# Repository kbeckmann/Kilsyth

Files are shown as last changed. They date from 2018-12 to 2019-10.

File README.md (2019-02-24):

# WIP! WIP! WIP! 
This repo is a work in progress and far from release-worthy. Please don't make your own boards and expect any kind of support. However, it might reach a stable point sometime in the future (as of 2019-01).

# Kilsyth: ECP5 FPGA + FT60x FIFO
Kilsyth is a piece of hardware that contains an FPGA (Lattice ECP5) and a SuperSpeed USB 3.0 FIFO-bridge (FT60x). The goal is to provide a platform to be able to transfer high speed data transfers between a PC and an FPGA. The FPGA in turn can do whatever - e.g. interface with SDR, video capture, act as a logic analyzer.

## Current status
It's still in the early bring-up phase. Initial verification shows that it actually seems to work.

### RevA
RevA is the first prototype and has been designed and built.

- [x] It doesn't smoke when powered up.
- [x] USB-C connector works but is messy to solder.
- [ ] Loopback test is almost in place. Using the proprietary driver, high bi-directional speeds are achieavable (> 98MB/s in both directions simultaneously). Just need to figure out some off-by-one errors...
- [ ] Bootloader to store a custom bitstream on the flash.

Errata:
- C9 is not a GPIO on ECP5 F12 and some other variants. To get the LED working put a jumper on pin 31 and 33 on the Wide connector.
- FT_CLK is not routed to a clock pin. Can be fixed with a bodge wire! Remove R50 and R36, swap their paths.
- JTAG connector has a funky footprint on the PCB because CCW vs Odd/Even pinout on the symbol vs footprint. But the PCB silk screen is accurate so don't worry - it's just a stupid pinout.
- Need to add pull-ups for the SPI flash.

### RevB
Ideas for RevB are still being collected. Feel free to suggest changes in an issue.

- Add support for reversible USB-C connector using [PI5USB30213A](https://www.diodes.com/products/connectivity-and-timing/switches-mux/protocol-switches/usb-switches/part/PI5USB30213A).

## Software usage (TODO)

Requires a patched migen and a patched ftdi library.. Nasty, I know, sorry.

```
Help:
$ python -m software.kilsyth -h

Run blinky:
$ python -m software.kilsyth run blinky

```

# Contact

Reach out to [@kbeckmann](https://twitter.com/kbeckmann) on Twitter or IRC/Freenode.

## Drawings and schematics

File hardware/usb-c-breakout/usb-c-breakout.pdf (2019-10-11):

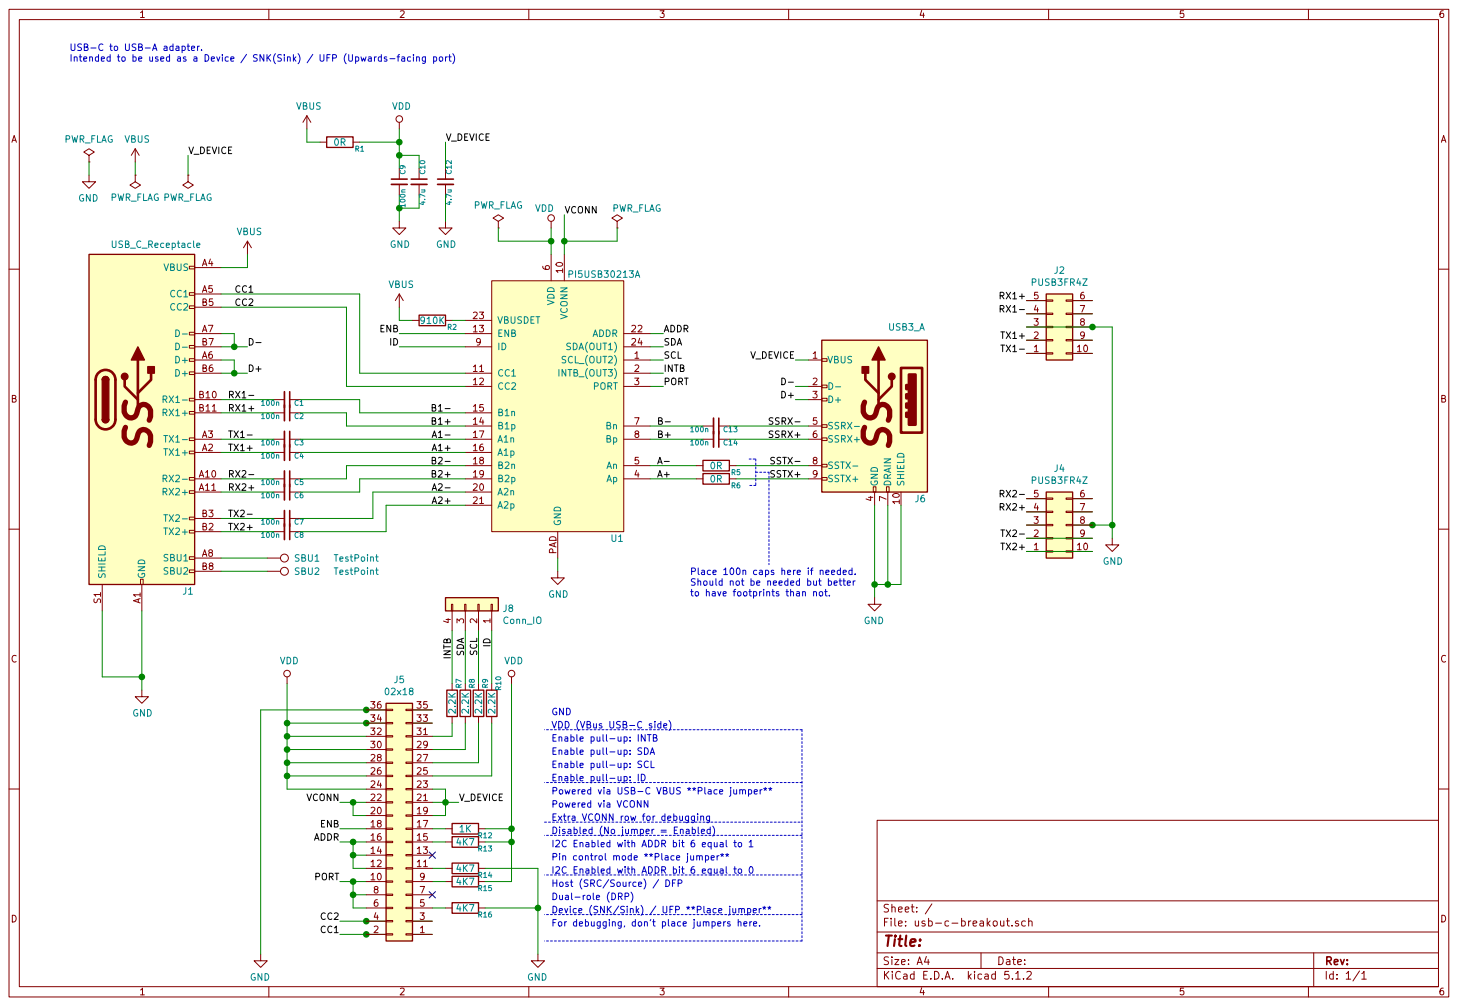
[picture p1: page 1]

USB-C to USB-A adapter.

to have footprints than not. R5 0R

Place 100n caps here if needed. Should not be needed but better

Enable pull-up: INTB
Enable pull-up: SDA
Enable pull-up: SCL
Enable pull-up: ID
Powered via USB-C VBUS **Place jumper**
For debugging, don't place jumpers here. Powered via VCONN
Extra VCONN row for debugging
Disabled (No jumper = Enabled)
I2C Enabled with ADDR bit 6 equal to 1
Pin control mode **Place jumper**
I2C Enabled with ADDR bit 6 equal to 0
Host (SRC/Source) / DFP
Dual-role (DRP)
Device (SNK/Sink) / UFP **Place jumper**

28 | 27
26 | 25
24 | 23

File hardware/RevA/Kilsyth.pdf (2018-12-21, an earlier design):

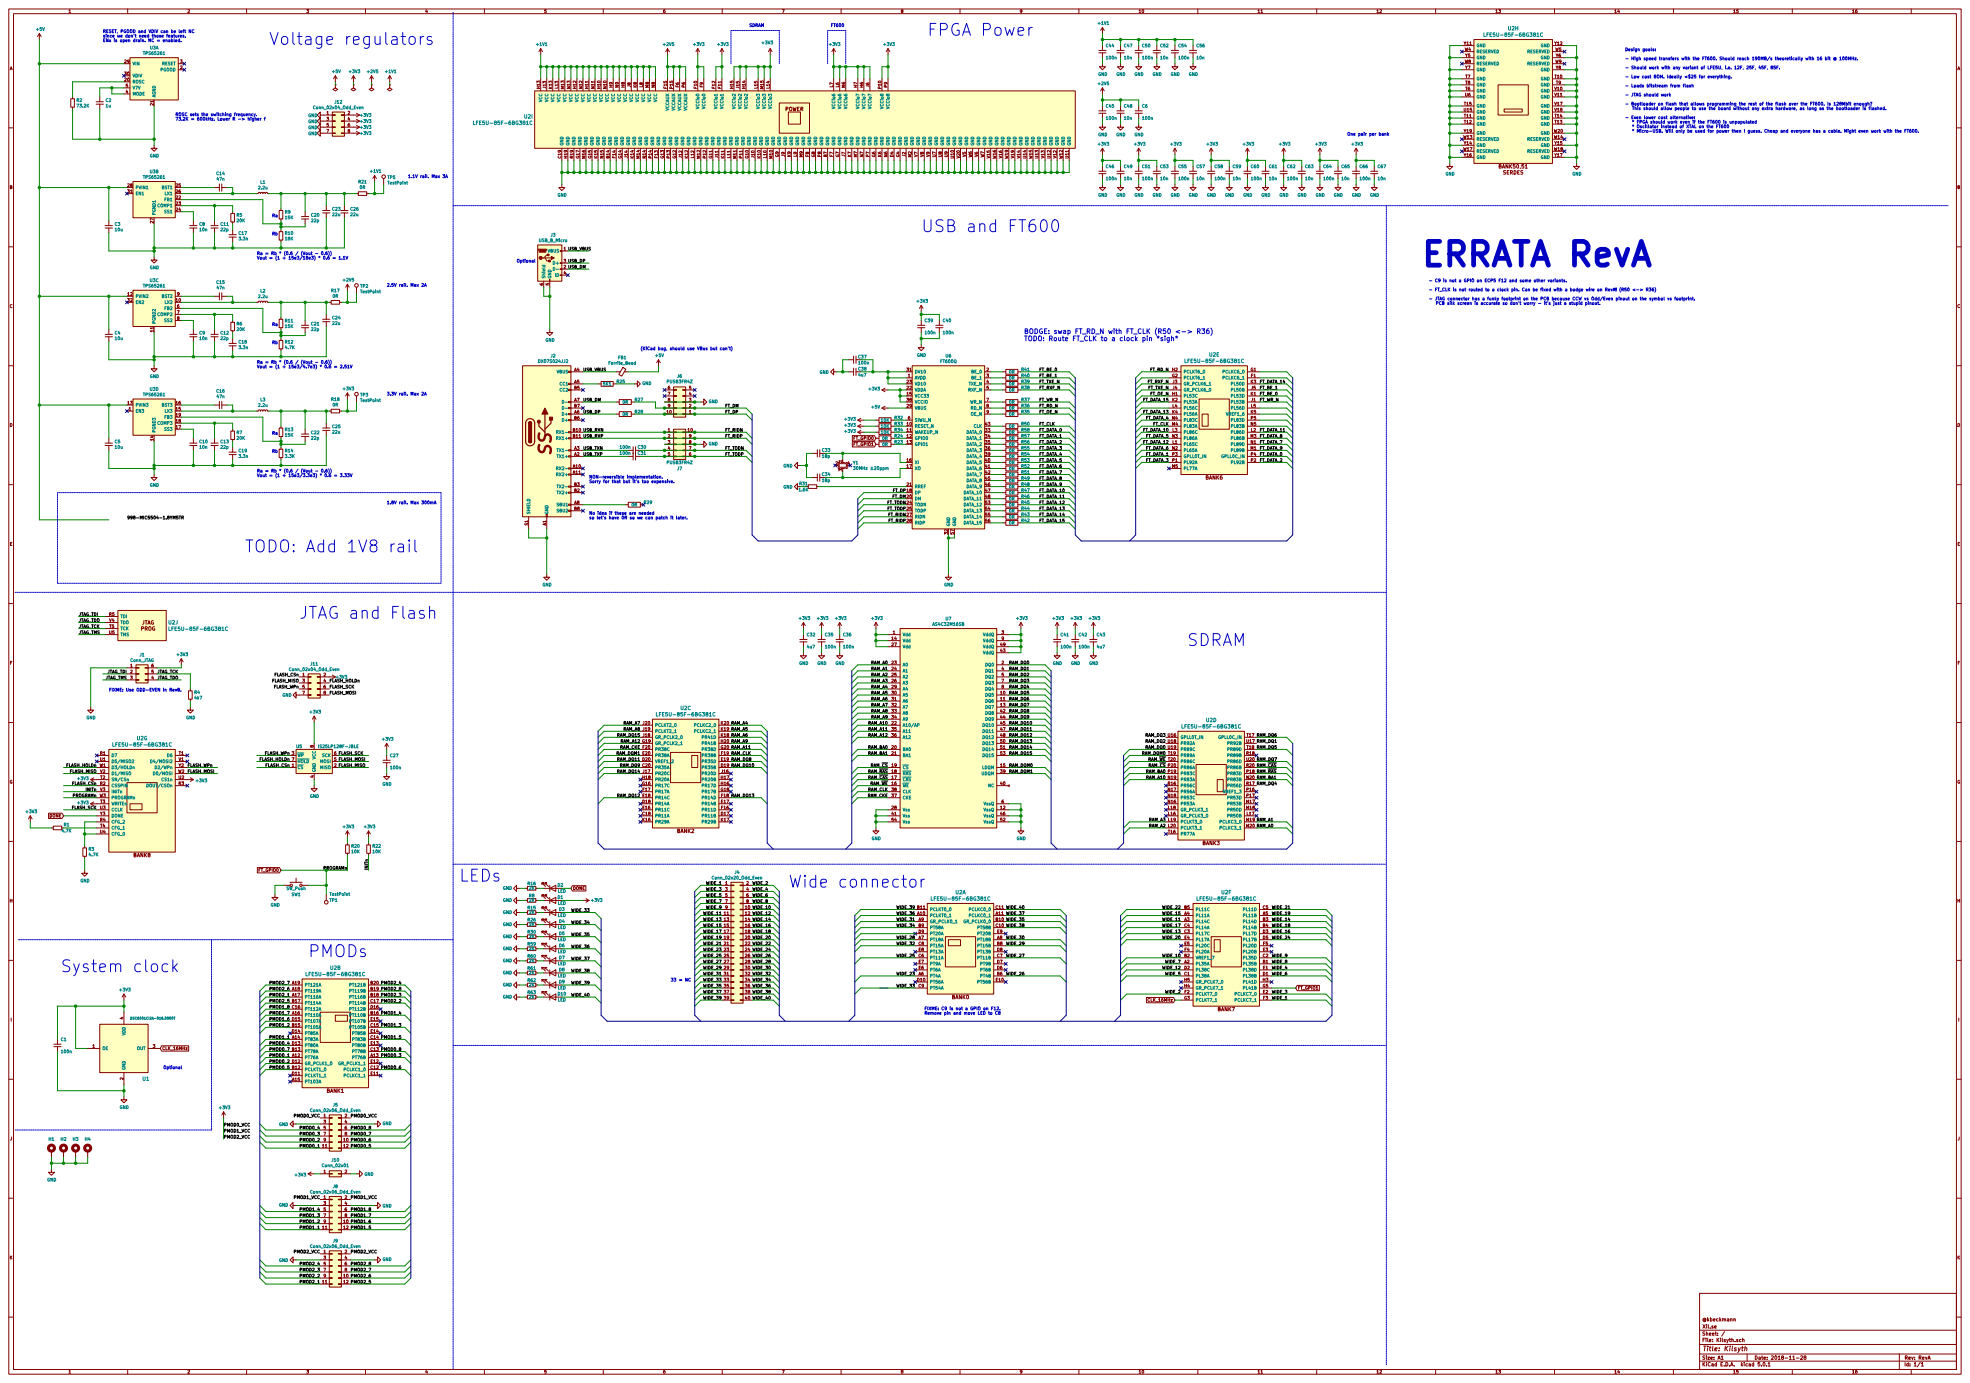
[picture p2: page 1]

Design goals:
- High speed transfers with the FT600. Should reach 190MB/s theoretically with 16 bit @ 100MHz.
- Should work with any variant of LFE5U, i.e. 12F, 25F, 45F, 85F.
- Low cost BOM. Ideally <$25 for everything. - Loads bitstream from flash

- JTAG should work
- Bootloader on flash that allows programming the rest of the flash over the FT600. Is 128Mbit enough?
This should allow people to use the board without any extra hardware, as long as the bootloader is flashed. - Even lower cost alternative:

* FPGA should work even if the FT600 is unpopulated
* Oscillator instead of XTAL on the FT600
* Micro-USB. Will only be used for power then I guess. Cheap and everyone has a cable. Might even work with the FT600.

+3V3 One pair per bank

Vout = (1 + 15e3/18e3) * 0.6 = 1.1V Ra Rb GND

- JTAG connector has a funky footprint on the PCB because CCW vs Odd/Even pinout on the symbol vs footprint.
PCB silk screen is accurate so don't worry - it's just a stupid pinout.

Vout = (1 + 15e3/4.7e3) * 0.6 = 2.51V Ra Rb GND

BODGE: swap FT_RD_N with FT_CLK (R50 <-> R36)
TODO: Route FT_CLK to a clock pin *sigh*

(KiCad bug, should use VBus but can't)

5 DATA_12 48 RXF_N | 0R

No idea if these are needed

FIXME: Use ODD-EVEN in RevB.

4 MOSI 5 SCK 6 HOLD 7 VCC

FIXME: C9 is not a GPIO on F12. Remove pin and move LED to C8

File: Kilsyth.sch Sheet: / Xil.se @kbeckmann

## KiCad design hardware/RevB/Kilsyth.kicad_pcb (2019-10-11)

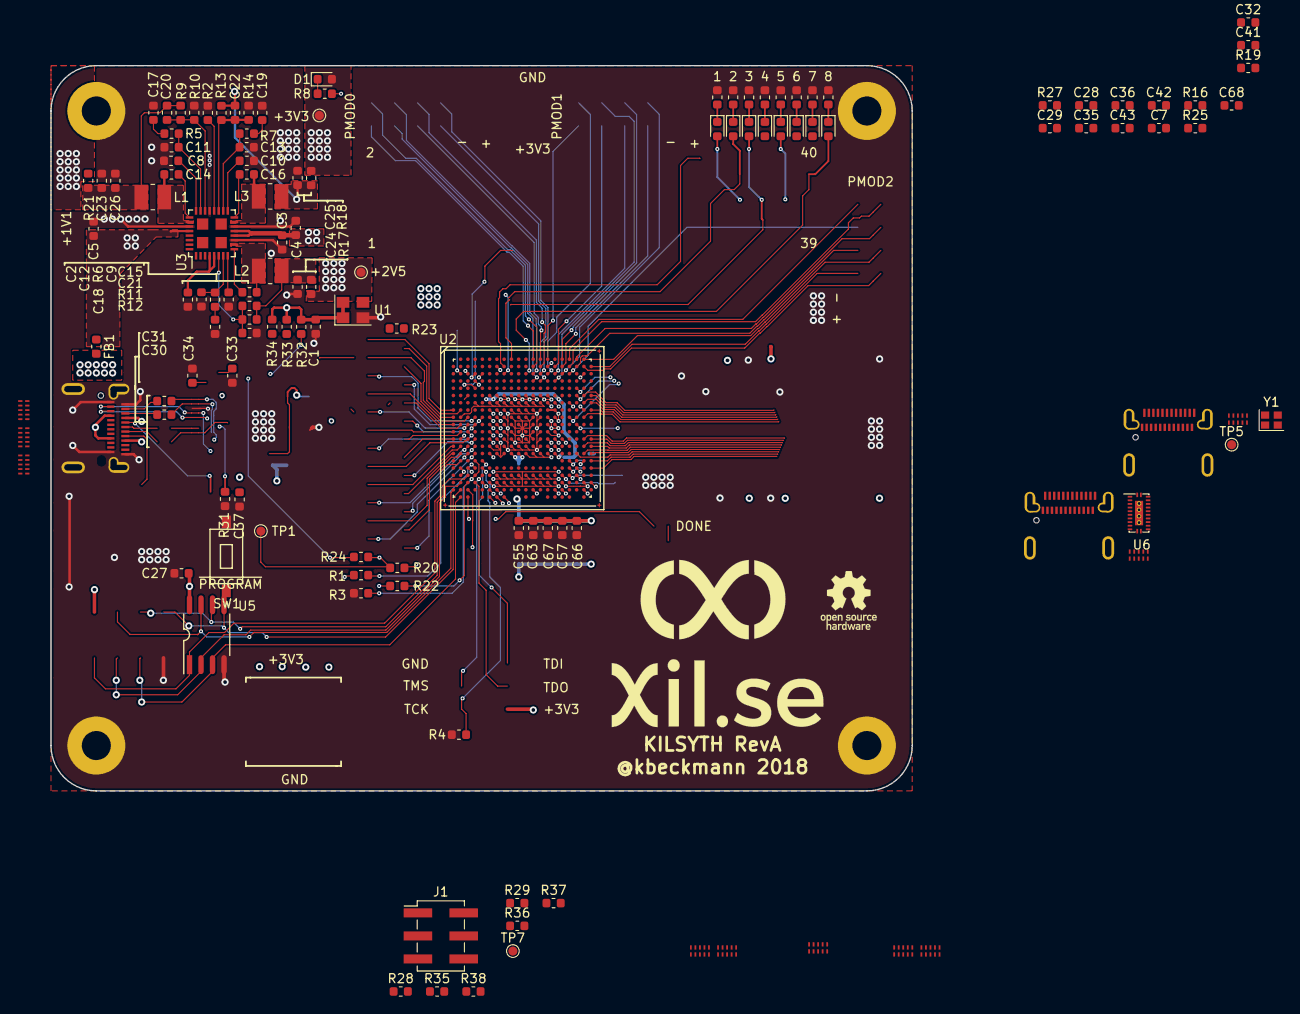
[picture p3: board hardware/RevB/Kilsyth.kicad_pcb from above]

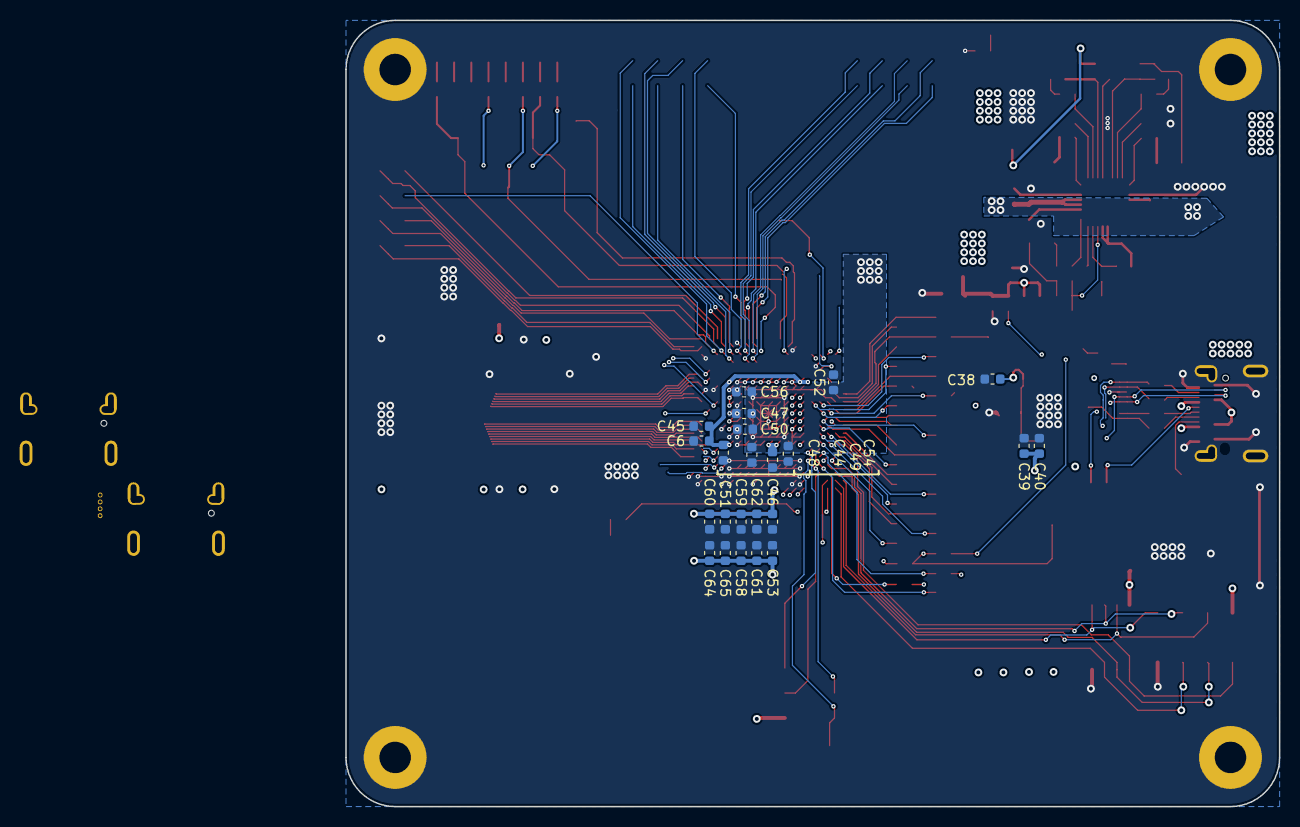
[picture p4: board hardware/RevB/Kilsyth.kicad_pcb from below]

Board: 4 copper layers, 95.0 x 80.0 mm, 154 parts (23 on the bottom side), 112 nets.

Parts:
C1, C6, C7, C27, C28, C29, C30, C31, C32, C35, C36, C37, C39, C40, C41, C42, C43, C44, C45, C46, C50, C51, C54, C55, C58, C60, C62, C64, C66, C68: 100n; C_0603_1608Metric
C2: 1u; C_0603_1608Metric
C3, C4, C5: 10u; C_0603_1608Metric
C8, C9, C10, C47, C48, C49, C52, C53, C56, C57, C59, C61, C63, C65, C67: 10n; C_0603_1608Metric
C11, C12, C13, C20, C21, C22: 22p; C_0603_1608Metric
C14, C15, C16: 47n; C_0603_1608Metric
C17, C18, C19: 3.3n; C_0603_1608Metric
C23, C24, C25, C26: 22u; C_0603_1608Metric
C33, C34: 18p; C_0603_1608Metric
C38: 4u7; C_0603_1608Metric
D1, D3, D4, D5, D6, D7, D8, D9, D10: LED; LED_0603_1608Metric
FB1: Ferrite_Bead; L_0603_1608Metric
H1, H2, H3, H4: MountingHole_3.2mm_M3_Pad
J1: Conn_JTAG; PinHeader_2x03_P2.54mm_Vertical_SMD
J2, J6, J7: DX07S024JJ2; USBC_DX07S024JJ2R1300
J3, J4, J5, J8, J9, J10, J11, J12, J13, J14: PUSB3FR4Z
L1, L2, L3: 2.2u; L_1008_1210
R1, R3, R12: 4.7K; R_0603_1608Metric
R2: 73.2K; R_0603_1608Metric
R4, R28: 4k7; R_0603_1608Metric
R5, R6, R7: 20K; R_0603_1608Metric
R8, R15, R26, R30, R59, R60, R61, R62, R63: 2K; R_0603_1608Metric
R9, R11, R13: 15K; R_0603_1608Metric
R10: 7K5; R_0603_1608Metric
R14: 3.3K; R_0603_1608Metric
R16, R27: 910K; R_0603_1608Metric
R17, R18, R21, R23, R24: 0R; R_0603_1608Metric
R19, R25: 2K2; R_0603_1608Metric
R20, R22, R32, R33, R34: 10K; R_0603_1608Metric
R29, R35, R37, R38: 10k; R_0603_1608Metric
R31: 1K6; R_0603_1608Metric
R36: 1k1; R_0603_1608Metric
SW1: SW_Push; SmallButton
TP1, TP2, TP3, TP5, TP7: TestPoint; TestPoint_Pad_D1.0mm
U1: DSC6001CI2A-016.0000T; Crystal_SMD_3225-4Pin_3.2x2.5mm
U2: LFE5UM-45F-6BG381C; BGA-381_pitch0.8mm_dia0.4mm
U3: TPS65261; S-PVQFN-N32
U5: IS25LP128F-JBLE; SOA008-150-208mil
U6: PI5USB30213A
Y1: 30MHz ±20ppm; Crystal_SMD_2016-4Pin_2.0x1.6mm

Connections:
+1V1: C44.1, C47.1, C50.1, C52.1, C54.1, C56.1, U2.H8, U2.H9, U2.H10, U2.H11, U2.H12, U2.H13, U2.J8, U2.J13, U2.K8, U2.K13, U2.L8, U2.L13, U2.M8, U2.M13, U2.N8, U2.N9, U2.N10, U2.N11, U2.N12, U2.N13
+1V8: R21.1, TP5.1
+2V5: C6.1, C45.1, C48.1, R17.1, TP2.1, U2.F6, U2.F15, U2.P6, U2.P15
+3V3: C1.1, C27.1, C39.1, C40.1, C46.1, C49.1, C51.1, C53.1, C55.1, C57.1, C58.1, C59.1, C60.1, C61.1, C62.1, C63.1, C64.1, C65.1, C66.1, C67.1, D1.2, J1.2, R1.1, R18.1, R19.2, R20.2, R22.2, R25.2, R28.1, R29.1, R32.2, R33.2, R34.2, R35.1, R36.1, R37.1, R38.1, TP3.1, U1.1, U1.4, U2.F9, U2.F10, U2.F11, U2.F12, U2.H6, U2.H7, U2.H14, U2.H15, U2.J6, U2.J15, U2.L6, U2.L7, U2.L14, U2.L15, U2.M6, U2.M15, U2.P9, U2.P10, U2.T2, U2.T3, U2.U2, U5.8
+5V: C3.1, C4.1, C5.1, J6.A4, J6.A9, J6.B4, J6.B9, J7.A4, J7.A9, J7.B4, J7.B9, U3.12, U3.13, U3.28, U3.29
/CC1: J2.A5, J4.5, J4.6, U6.11
/CC2: J2.B5, J4.4, J4.7, U6.12
/FLASH_CSn: R28.2, U2.R2, U5.1
/FLASH_HOLDn: R29.2, U2.W1, U5.7
/FLASH_MISO: R38.2, U2.V2, U5.2
/FLASH_MOSI: R37.2, U2.W2, U5.5
/FLASH_SCK: R36.2, U2.U3, U5.6
/FLASH_WPn: R35.2, U2.Y2, U5.3
/HDRX0_D0CH0_N: J6.B10, J8.5, J8.6, U2.Y6
/HDRX0_D0CH0_P: J6.B11, J8.4, J8.7, U2.Y5
/HDRX0_D0CH1_N: J6.A10, J9.5, J9.6, U2.Y8
/HDRX0_D0CH1_P: J6.A11, J9.4, J9.7, U2.Y7
/HDRX0_D1CH0_N: J7.B10, J11.5, J11.6, U2.Y15
/HDRX0_D1CH0_P: J7.B11, J11.4, J11.7, U2.Y14
/HDRX0_D1CH1_N: J7.A10, J12.5, J12.6, U2.Y17
/HDRX0_D1CH1_P: J7.A11, J12.4, J12.7, U2.Y16
/HDTX0_D0CH0_N: C29.2, J8.2, J8.9, U2.W5
/HDTX0_D0CH0_P: C32.2, J8.1, J8.10, U2.W4
/HDTX0_D0CH1_N: C35.2, J9.2, J9.9, U2.W9
/HDTX0_D0CH1_P: C36.2, J9.1, J9.10, U2.W8
/HDTX0_D1CH0_N: C41.2, J11.2, J11.9, U2.W14
/HDTX0_D1CH0_P: C42.2, J11.1, J11.10, U2.W13
/HDTX0_D1CH1_N: C43.2, J12.2, J12.9, U2.W18
/HDTX0_D1CH1_P: C68.2, J12.1, J12.10, U2.W17
/INITn: R22.1, U2.V3
/JTAG_TCK: J1.4, R4.1, U2.T5
/JTAG_TDI: J1.3, U2.R5
/JTAG_TDO: J1.6, U2.V4
/JTAG_TMS: J1.5, U2.U5
/REFCLK_D0_N: J6.B8, J10.4, J10.7, U2.Y12
/REFCLK_D0_P: J6.A8, J10.5, J10.6, U2.Y11
/REFCLK_D1_N: J7.B8, J10.1, J10.10, U2.W20
/REFCLK_D1_P: J7.A8, J10.2, J10.9, U2.Y19
/RX1+: J2.B11, J3.5, J3.6, U6.14
/RX1-: J2.B10, J3.4, J3.7, U6.15
/RX2+: J2.A11, J5.4, J5.7, U6.19
/RX2-: J2.A10, J5.5, J5.6, U6.18
/TX1+: C31.1, J2.A2, J3.2, J3.9
/TX1-: C30.1, J2.A3, J3.1, J3.10
/TX2+: C28.1, J2.B2, J5.1, J5.10
/TX2-: C7.1, J2.B3, J5.2, J5.9
/USBC0_CC1: J6.A5, J13.5, J13.6
/USBC0_CC2: J6.B5, J13.4, J13.7
/USBC0_USB_N: J6.A7, J6.B7, J13.2, J13.9
/USBC0_USB_P: J6.A6, J6.B6, J13.1, J13.10
/USBC1_CC1: J7.A5, J14.5, J14.6
/USBC1_CC2: J7.B5, J14.4, J14.7
/USBC1_USB_N: J7.A7, J7.B7, J14.2, J14.9
/USBC1_USB_P: J7.A6, J7.B6, J14.1, J14.10
/USB_D+: J2.A6, J2.B6, J4.2, J4.9
/USB_D-: J2.A7, J2.B7, J4.1, J4.10
FT_GPIO0: R20.1, R24.2, R25.1, SW1.2, TP1.1, U2.W3
FT_GPIO1: R19.1, R23.2
GND: C1.2, C2.2, C3.2, C4.2, C5.2, C6.2, C8.2, C9.2, C10.2, C11.2, C12.2, C13.2, C17.2, C18.2, C19.2, C23.2, C24.2, C25.2, C26.2, C27.2, C33.1, C34.1, C37.2, C38.2, C39.2, C40.2, C44.2, C45.2, C46.2, C47.2, C48.2, C49.2, C50.2, C51.2, C52.2, C53.2, C54.2, C55.2, C56.2, C57.2, C58.2, C59.2, C60.2, C61.2, C62.2, C63.2, C64.2, C65.2, C66.2, C67.2, H1.1, H2.1, H3.1, H4.1, J1.1, J2.A1, J2.A12, J2.B1, J2.B12, J2.S1, J3.3, J3.8, J4.3, J4.8, J5.3, J5.8, J6.A1, J6.A12, J6.B1, J6.B12, J6.S1, J7.A1, J7.A12, J7.B1, J7.B12, J7.S1, J8.3, J8.8, J9.3, J9.8, J10.3, J10.8, J11.3, J11.8, J12.3, J12.8, J13.3, J13.8, J14.3, J14.8, R2.2, R3.1, R4.2, R8.2, R10.2, R12.2, R14.2, R15.2, R26.2, R30.2, R31.2, R59.2, R60.2, R61.2, R62.2, R63.2, SW1.1, U1.2, U2.B7, U2.B14, U2.C19, U2.D4, U2.F7, U2.F8, U2.F13, U2.F14, U2.G4, U2.G6, U2.G7, U2.G8, U2.G9, U2.G10, U2.G11, U2.G12, U2.G13, U2.G14, U2.G15, U2.G17, U2.H19, U2.J2, U2.J7, U2.J9, U2.J10, U2.J11, U2.J12, U2.J14, U2.K6, U2.K7, U2.K9, U2.K10, U2.K11, U2.K12, U2.K14, U2.K15, U2.L9, U2.L10, U2.L11, U2.L12, U2.M2, U2.M7, U2.M9, U2.M10, U2.M11, U2.M12, U2.M14, U2.M16, U2.N6, U2.N7, U2.N14, U2.N15, U2.P7, U2.P8, U2.P11, U2.P12, U2.P13, U2.P14, U2.R19, U2.U7, U2.U8, U2.U9, U2.U10, U2.U11, U2.U12, U2.U13, U2.U14, U2.V5, U2.V6, U2.V7, U2.V8, U2.V9, U2.V12, U2.V13, U2.V14, U2.V15, U2.V16, U2.V19, U2.V20, U2.W6, U2.W7, U2.W12, U2.W15, U2.W16, U2.W19, U3.11, U3.14, U3.21, U3.27, U5.4, U6.3, U6.13, U6.PAD
unnamed: C2.1, U3.4, U3.5
unnamed: C7.2, U6.20
unnamed: C8.1, U3.24
unnamed: C9.1, U3.8
unnamed: C10.1, U3.17
unnamed: C11.1, R5.1, U3.23
unnamed: C12.1, R6.1, U3.7
unnamed: C13.1, R7.1, U3.18
unnamed: C14.1, U3.25
unnamed: C14.2, L1.1, U3.26
unnamed: C15.1, U3.9
unnamed: C15.2, L2.1, U3.10
unnamed: C16.1, U3.16
unnamed: C16.2, L3.1, U3.15
unnamed: C17.1, R5.2
unnamed: C18.1, R6.2
unnamed: C19.1, R7.2
unnamed: C20.1, C23.1, C26.1, L1.2, R9.1, R21.2
unnamed: C20.2, R9.2, R10.1, U3.22
unnamed: C21.1, C24.1, L2.2, R11.1, R17.2
unnamed: C21.2, R11.2, R12.1, U3.6
unnamed: C22.1, C25.1, L3.2, R13.1, R18.2
unnamed: C22.2, R13.2, R14.1, U3.19
unnamed: C28.2, U6.21
unnamed: C29.1, J6.A3
unnamed: C30.2, U6.17
unnamed: C31.2, U6.16
unnamed: C32.1, J6.A2
unnamed: C33.2, Y1.1
unnamed: C34.2, Y1.3
unnamed: C35.1, J6.B3
unnamed: C36.1, J6.B2
unnamed: C41.1, J7.A3
unnamed: C42.1, J7.A2
unnamed: C43.1, J7.B3
unnamed: C68.1, J7.B2
unnamed: D1.1, R8.1
unnamed: D3.1, R15.1
unnamed: D4.1, R26.1
unnamed: D5.1, R30.1
unnamed: D6.1, R59.1
unnamed: D7.1, R60.1
unnamed: D8.1, R61.1
unnamed: D9.1, R62.1
unnamed: D10.1, R63.1
unnamed: FB1.2, J2.A4, J2.A9, J2.B4, J2.B9
unnamed: R1.2, U2.T4
unnamed: R2.1, U3.20
unnamed: R3.2, U2.R4, U2.U4
unnamed: R16.2, U6.23
unnamed: TP7.1, U2.Y3
VBUS: FB1.1, R16.1, R27.2, U6.6
VD10: C37.1, C38.1

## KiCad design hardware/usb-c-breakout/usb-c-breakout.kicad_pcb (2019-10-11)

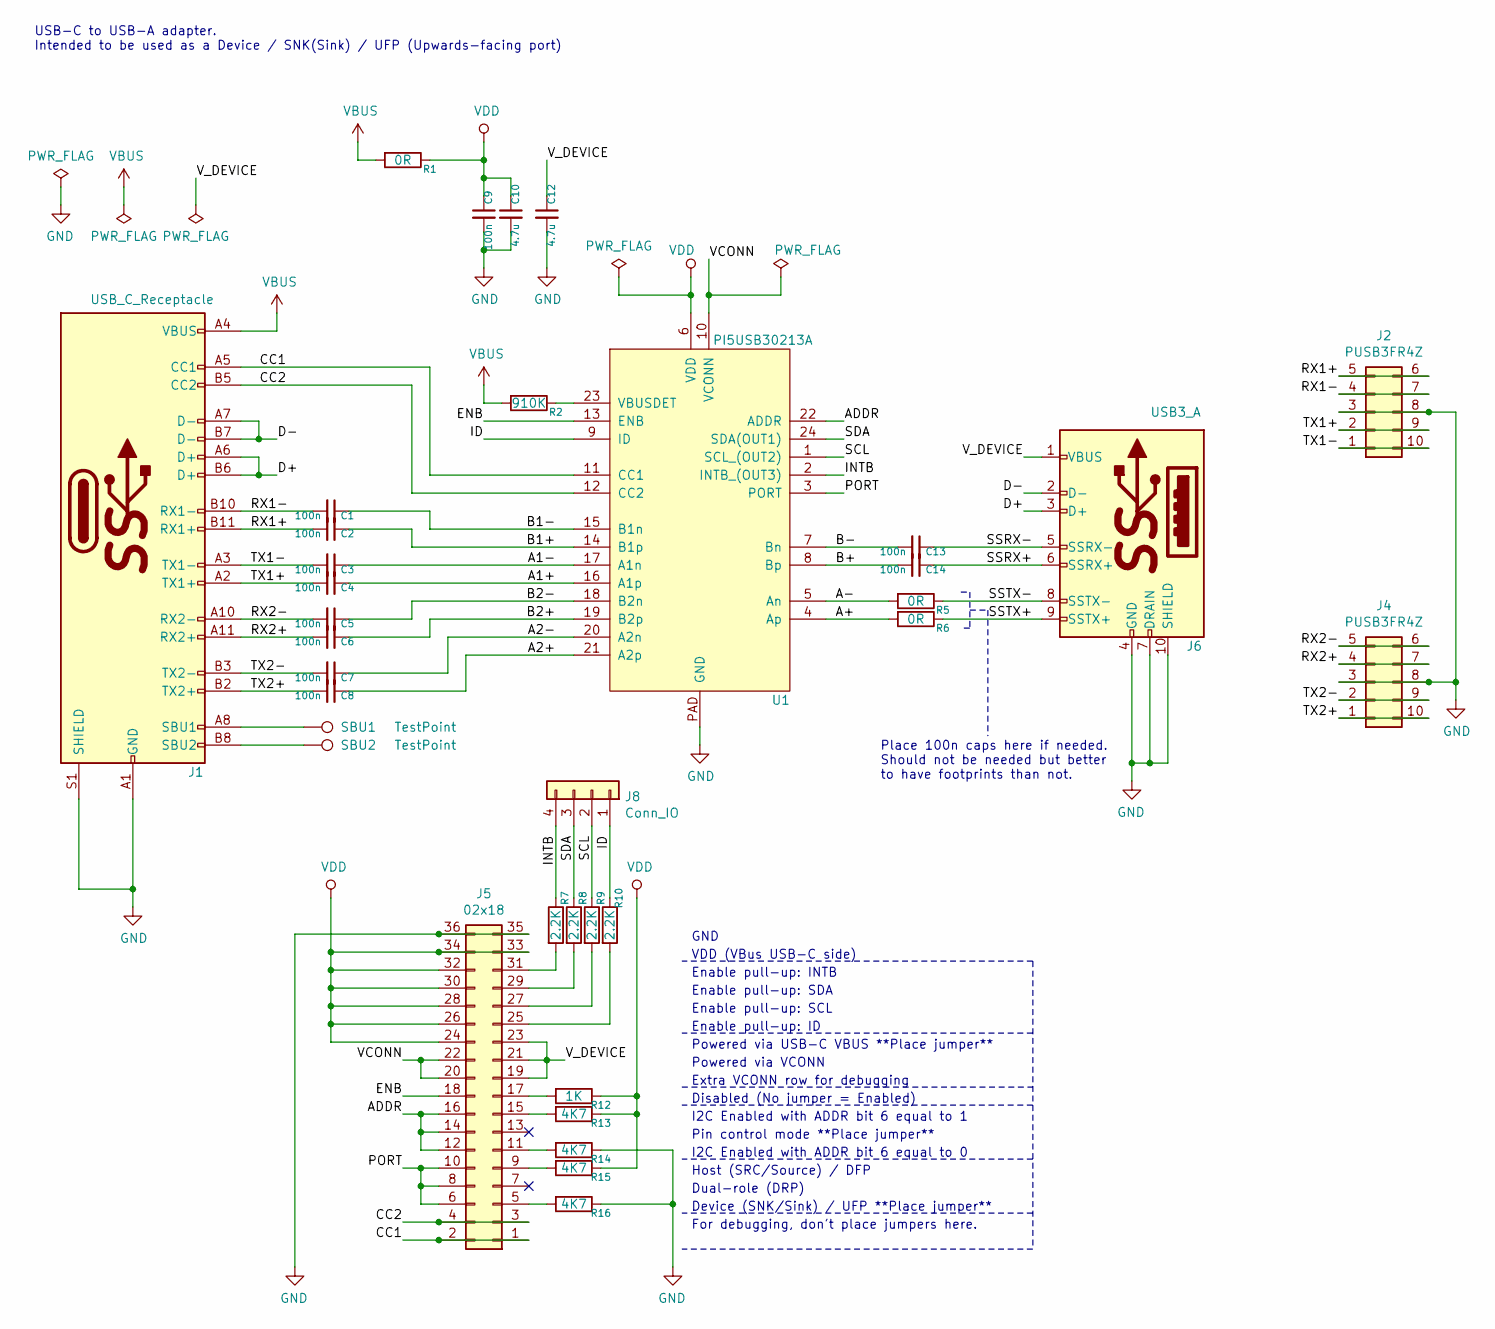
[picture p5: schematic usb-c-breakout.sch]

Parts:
C1, C2, C3, C4, C5, C6, C7, C8, C9, C13, C14: 100n; C_0402_1005Metric
C10, C12: 4.7u; C_0603_1608Metric
J1: USB_C_Receptacle; USB_C_Receptacle_CUI_UJ31-CH-31-SMT-TR
J2, J4: PUSB3FR4Z; Mouser 771-PUSB3FR4Z
J5: 02x18; PinHeader_2x18_P2.54mm_Vertical
J6: USB3_A; USB3_A_Female_Vertical
J8: Conn_IO; PinHeader_1x04_P2.54mm_Vertical
R1: 0R; R_0603_1608Metric
R2: 910K; R_0402_1005Metric
R5, R6: 0R; R_0402_1005Metric
R7, R8, R9, R10: 2.2K; R_0402_1005Metric
R12: 1K; R_0402_1005Metric
R13, R14, R15, R16: 4K7; R_0402_1005Metric
SBU1, SBU2: TestPoint; TestPoint_Pad_D1.0mm
U1: PI5USB30213A; Mouser PI5USB30213AXEAEX

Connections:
/A1+: C4.1, U1.16 (A1p)
/A1-: C3.1, U1.17 (A1n)
/A2+: C8.1, U1.21 (A2p)
/A2-: C7.1, U1.20 (A2n)
/A+: R6.2, U1.4 (Ap)
/A-: R5.2, U1.5 (An)
/ADDR: J5.12, J5.14, J5.16, U1.22 (ADDR)
/B1+: C2.1, U1.14 (B1p)
/B1-: C1.1, U1.15 (B1n)
/B2+: C6.1, U1.19 (B2p)
/B2-: C5.1, U1.18 (B2n)
/B+: C14.2, U1.8 (Bp)
/B-: C13.2, U1.7 (Bn)
/CC1: J1.A5 (CC1), J5.1, J5.2, U1.11 (CC1)
/CC2: J1.B5 (CC2), J5.3, J5.4, U1.12 (CC2)
/D+: J1.A6 (D+), J1.B6 (D+), J6.3 (D+)
/D-: J1.A7 (D-), J1.B7 (D-), J6.2 (D-)
/ENB: J5.18, U1.13 (ENB)
/ID: J8.1, R10.1, U1.9 (ID)
/INTB: J8.4, R7.1, U1.2 (INTB_(OUT3))
/PORT: J5.6, J5.8, J5.10, U1.3 (PORT)
/RX1+: C2.2, J1.B11 (RX1+), J2.5, J2.6
/RX1-: C1.2, J1.B10 (RX1-), J2.4, J2.7
/RX2+: C6.2, J1.A11 (RX2+), J4.4, J4.7
/RX2-: C5.2, J1.A10 (RX2-), J4.5, J4.6
/SCL: J8.2, R9.1, U1.1 (SCL_(OUT2))
/SDA: J8.3, R8.1, U1.24 (SDA(OUT1))
/SSRX+: C14.1, J6.6 (SSRX+)
/SSRX-: C13.1, J6.5 (SSRX-)
/SSTX+: J6.9 (SSTX+), R6.1
/SSTX-: J6.8 (SSTX-), R5.1
/TX1+: C4.2, J1.A2 (TX1+), J2.2, J2.9
/TX1-: C3.2, J1.A3 (TX1-), J2.1, J2.10
/TX2+: C8.2, J1.B2 (TX2+), J4.1, J4.10
/TX2-: C7.2, J1.B3 (TX2-), J4.2, J4.9
/VCONN: J5.20, J5.22, U1.10 (VCONN)
/V_DEVICE: C12.1, J5.19, J5.21, J5.23, J6.1 (VBUS)
GND: C9.2, C10.2, C12.2, J1.A1 (GND), J1.A12 (GND), J1.B1 (GND), J1.B12 (GND), J1.S1 (SHIELD), J2.3, J2.8, J4.3, J4.8, J5.35, J5.36, J6.4 (GND), J6.7 (DRAIN), J6.10 (SHIELD), R14.1, R16.1, U1.PAD (GND)
unnamed: J1.A8 (SBU1), SBU1.1
unnamed: J1.B8 (SBU2), SBU2.1
unnamed: J5.5, R16.2
unnamed: J5.9, R15.2
unnamed: J5.11, R14.2
unnamed: J5.15, R13.2
unnamed: J5.17, R12.2
unnamed: J5.25, R10.2
unnamed: J5.27, R9.2
unnamed: J5.29, R8.2
unnamed: J5.31, R7.2
unnamed: R2.1, U1.23 (VBUSDET)
VBUS: J1.A4 (VBUS), J1.A9 (VBUS), J1.B4 (VBUS), J1.B9 (VBUS), R1.2, R2.2
VDD: C9.1, C10.1, J5.24, J5.26, J5.28, J5.30, J5.32, J5.33, J5.34, R1.1, R12.1, R13.1, R15.1, U1.6 (VDD)

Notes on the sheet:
USB-C to USB-A adapter. Intended to be used as a Device / SNK(Sink) / UFP (Upwards-facing port)
Place 100n caps here if needed. Should not be needed but better to have footprints than not.
Extra VCONN row for debugging
For debugging, don't place jumpers here.
Powered via VCONN
Powered via USB-C VBUS **Place jumper**
Device (SNK/Sink) / UFP **Place jumper**
Dual-role (DRP)
Host (SRC/Source) / DFP
I2C Enabled with ADDR bit 6 equal to 0
Pin control mode **Place jumper**
I2C Enabled with ADDR bit 6 equal to 1
Disabled (No jumper = Enabled)
Enable pull-up: ID
Enable pull-up: SCL
Enable pull-up: SDA
Enable pull-up: INTB
VDD (VBus USB-C side)
GND

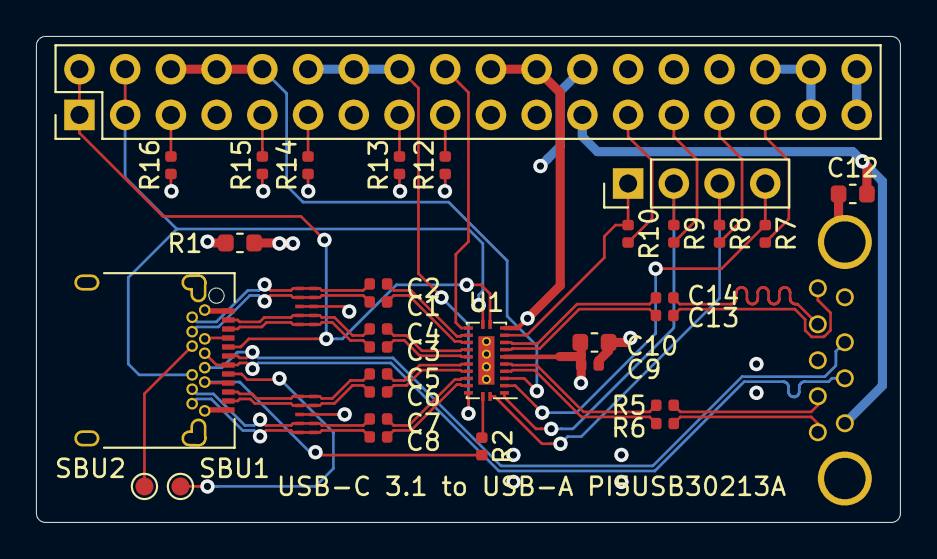
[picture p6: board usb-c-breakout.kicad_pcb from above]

Board: 4 copper layers, 48.0 x 27.0 mm, 35 parts (0 on the bottom side), 52 nets.

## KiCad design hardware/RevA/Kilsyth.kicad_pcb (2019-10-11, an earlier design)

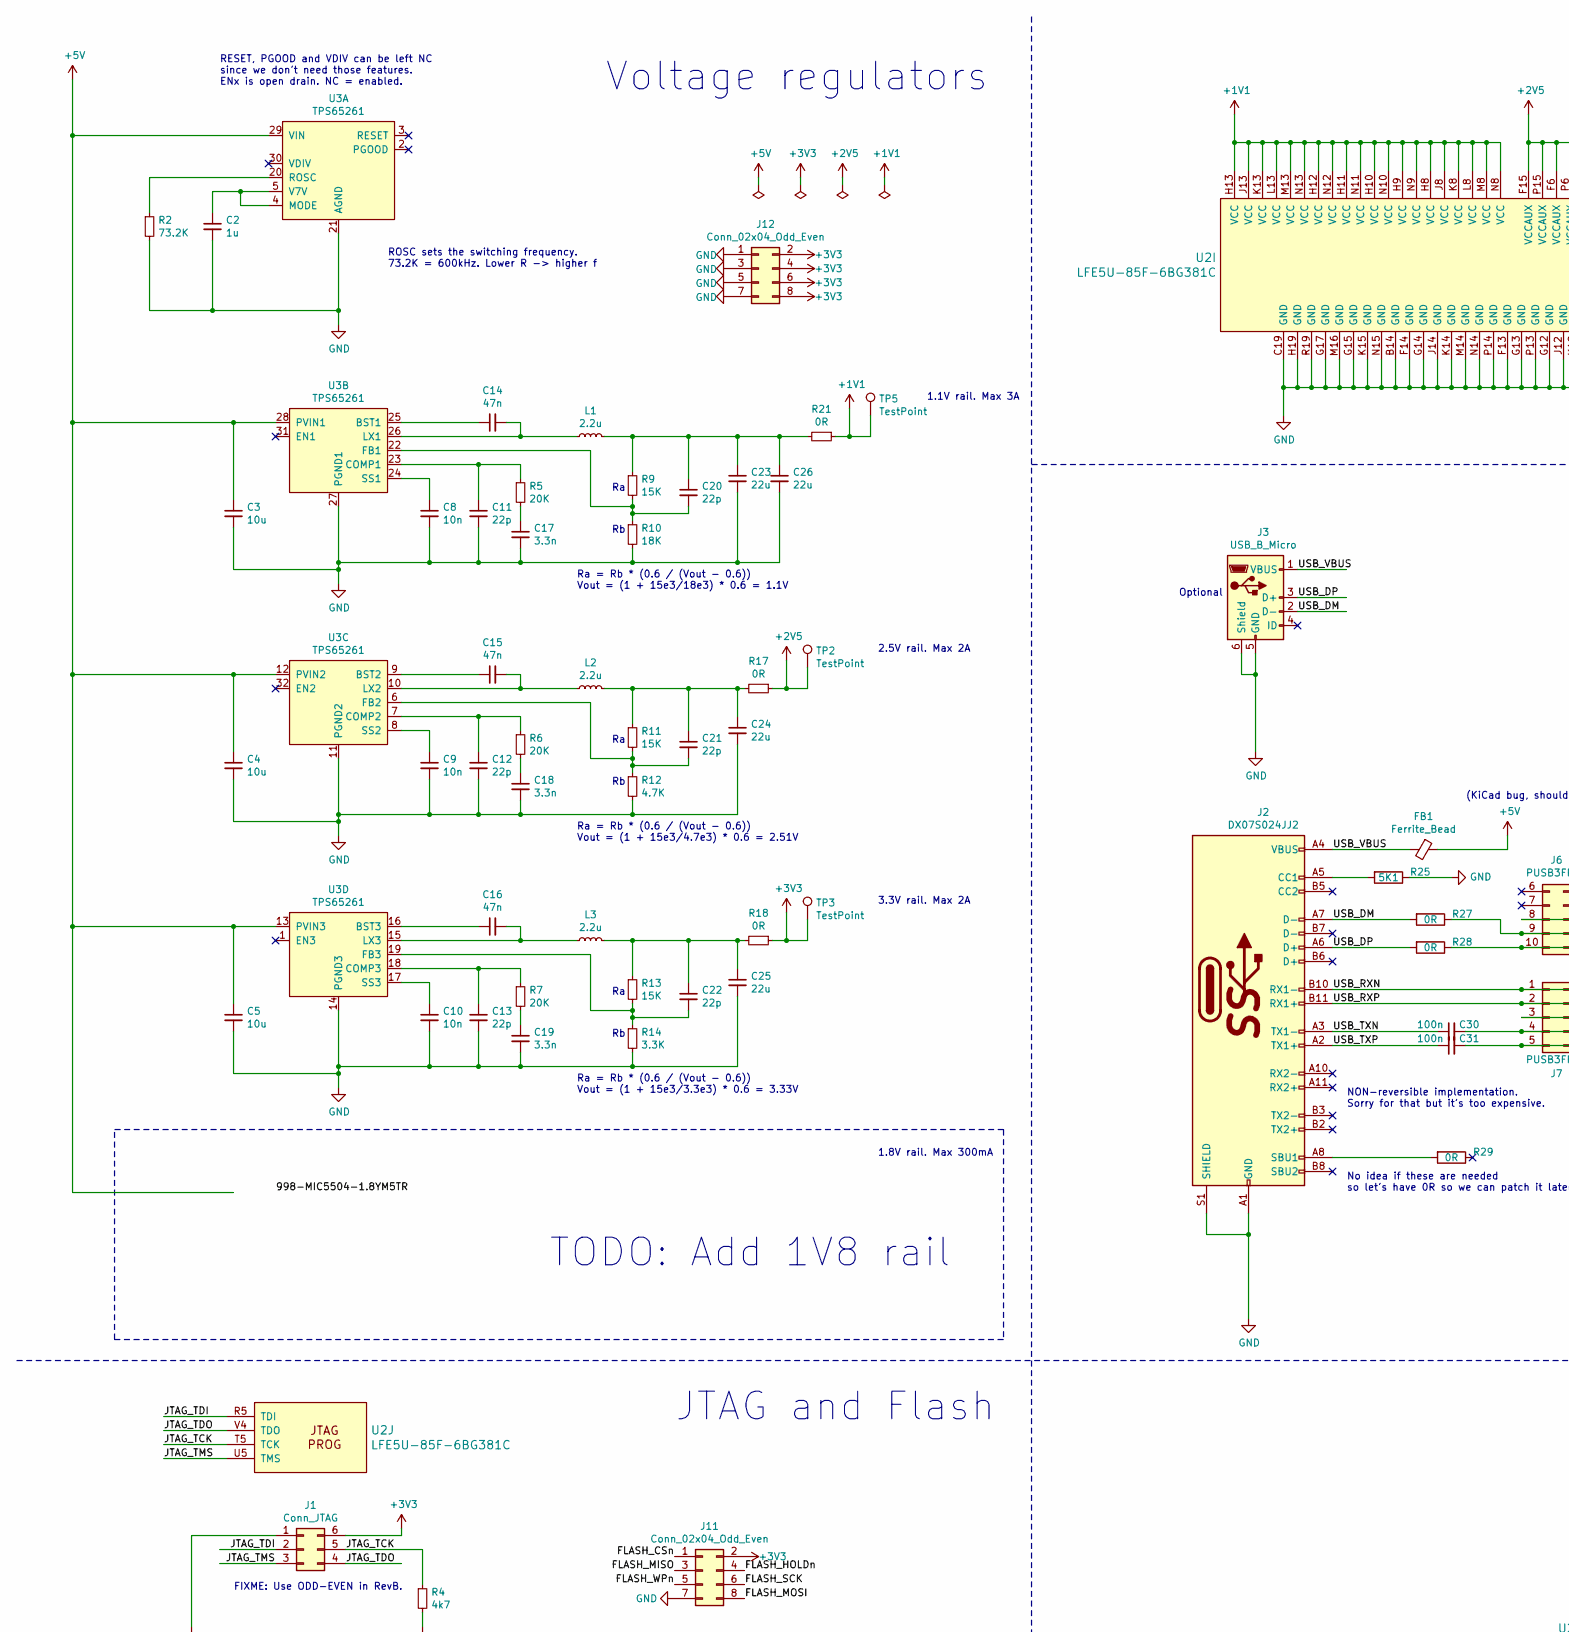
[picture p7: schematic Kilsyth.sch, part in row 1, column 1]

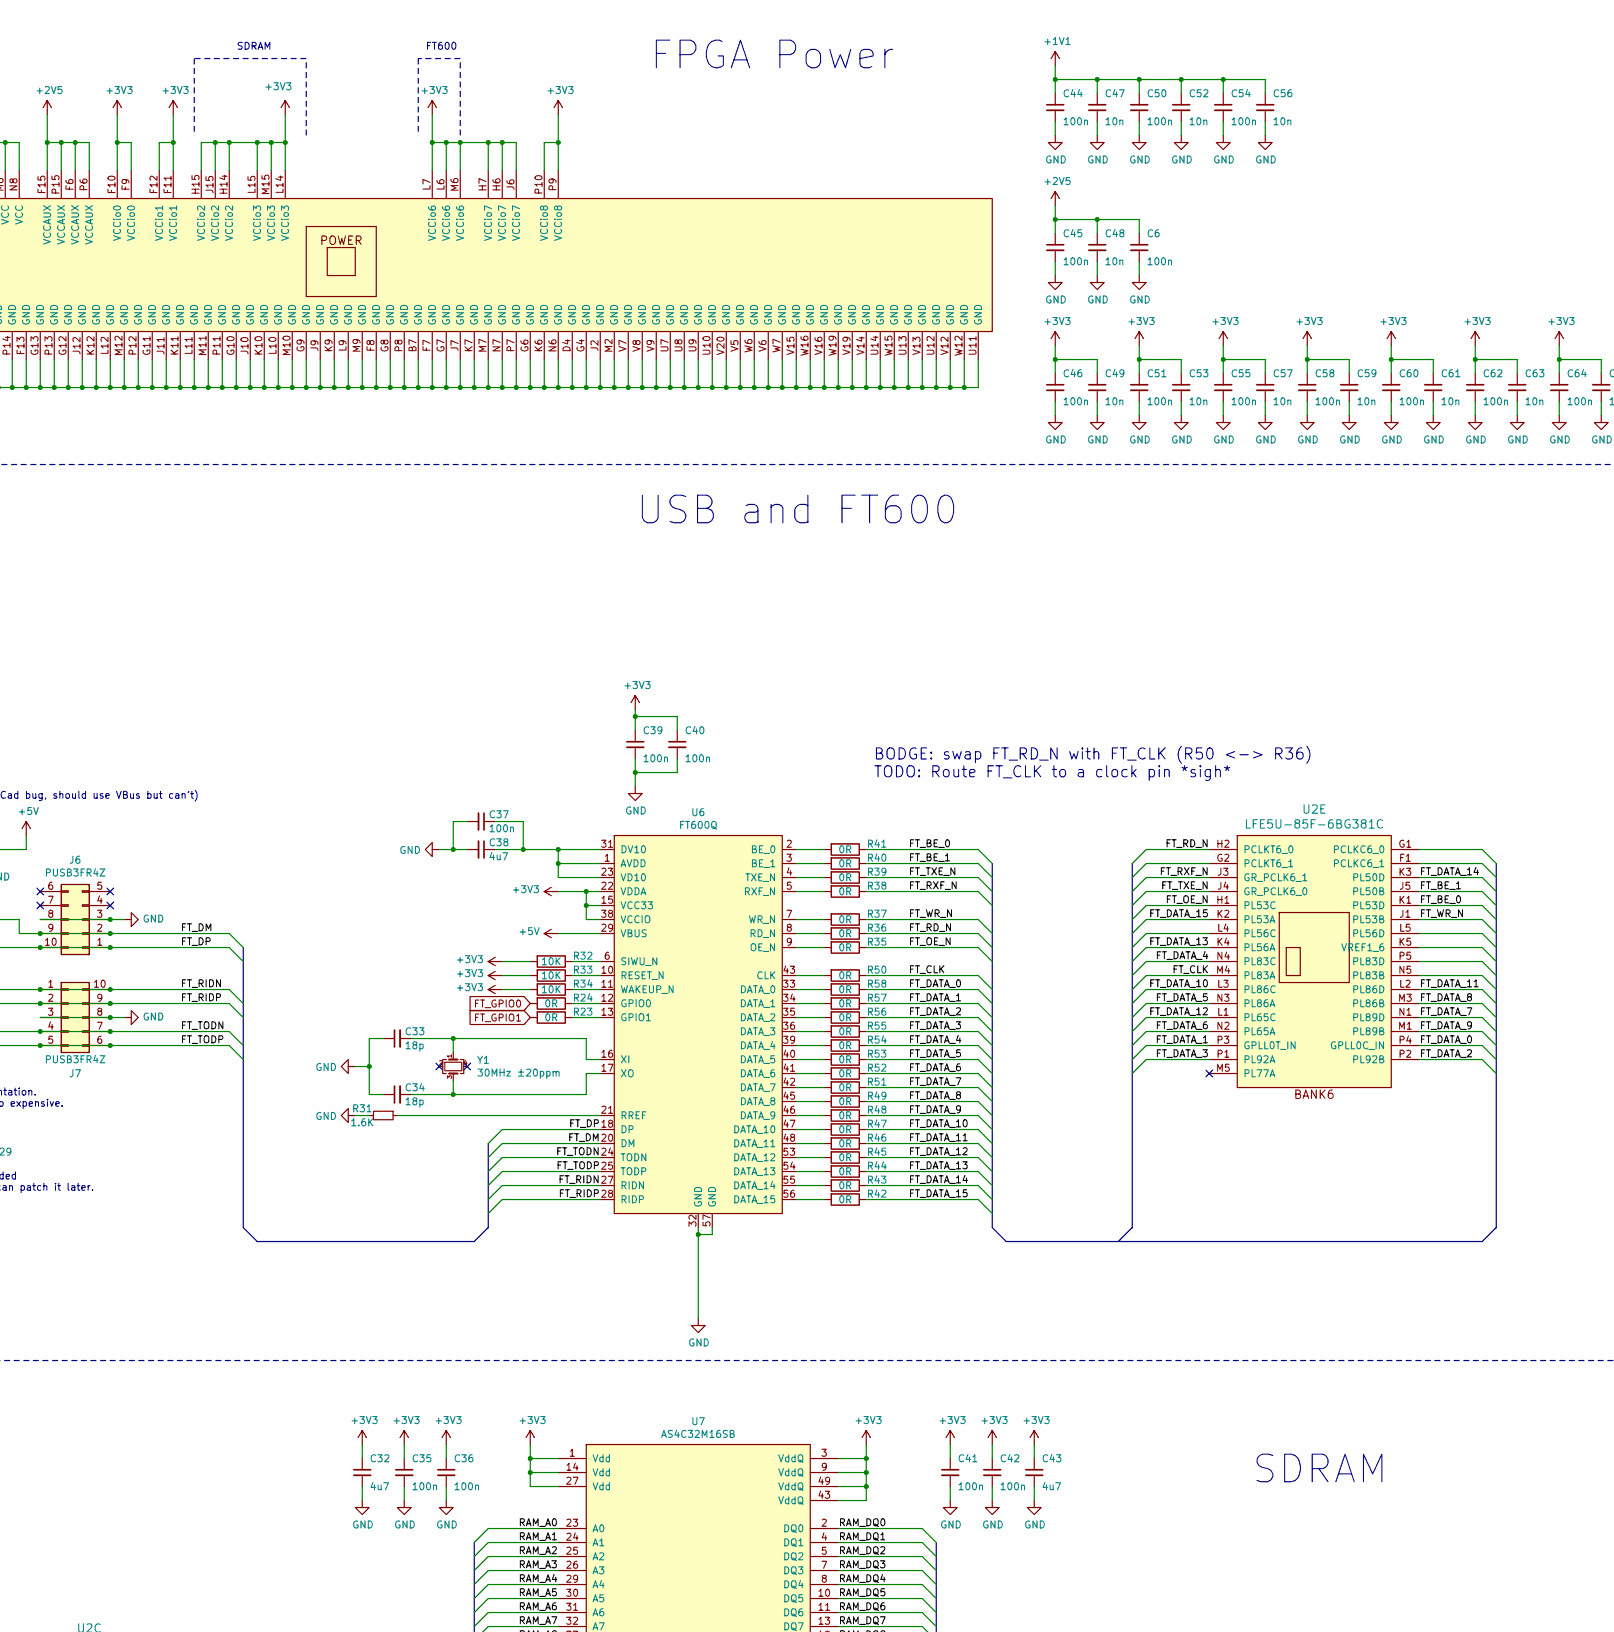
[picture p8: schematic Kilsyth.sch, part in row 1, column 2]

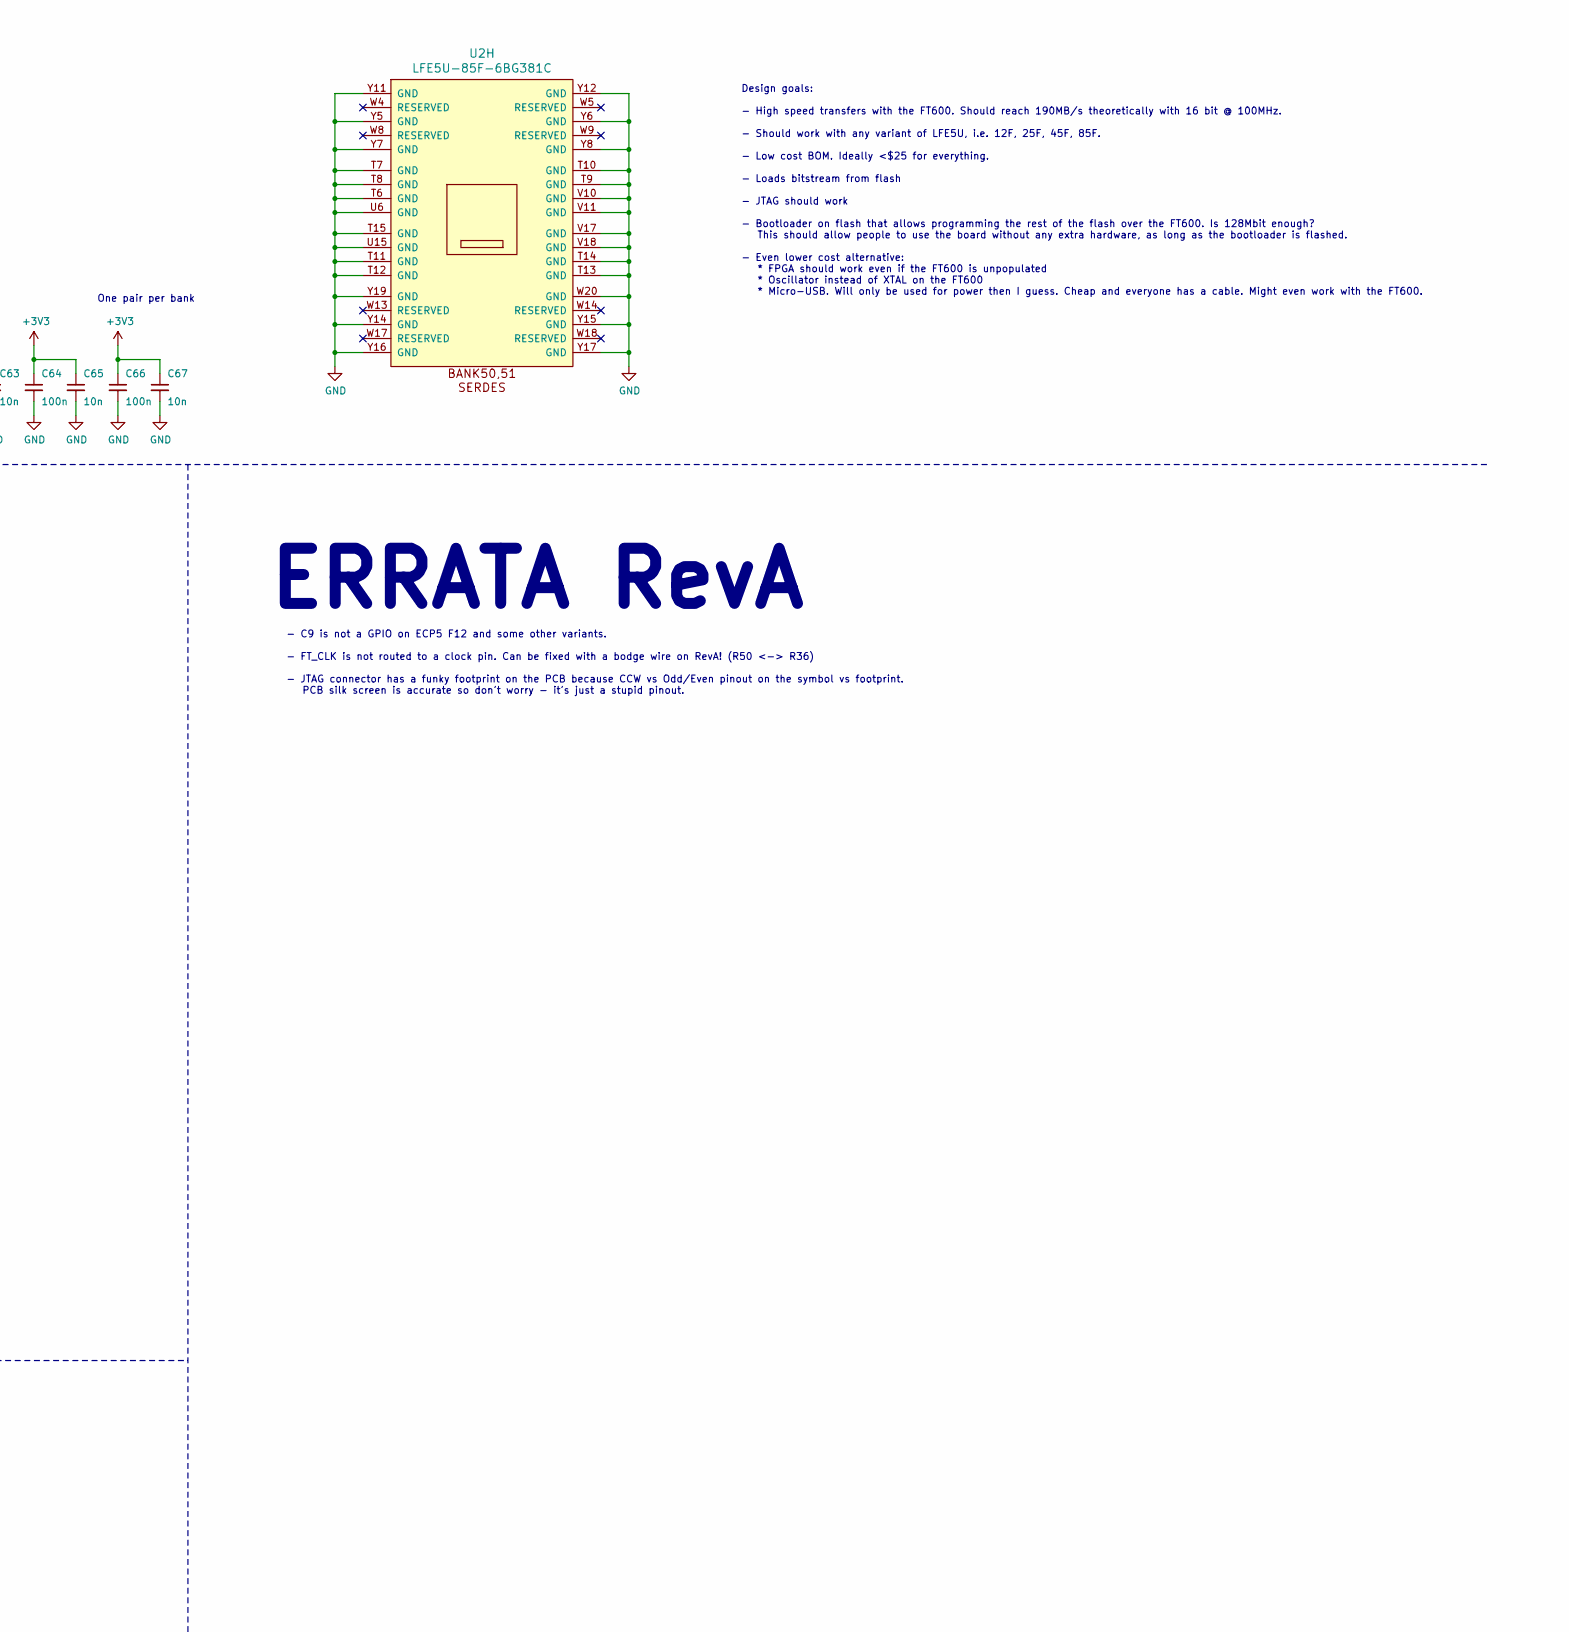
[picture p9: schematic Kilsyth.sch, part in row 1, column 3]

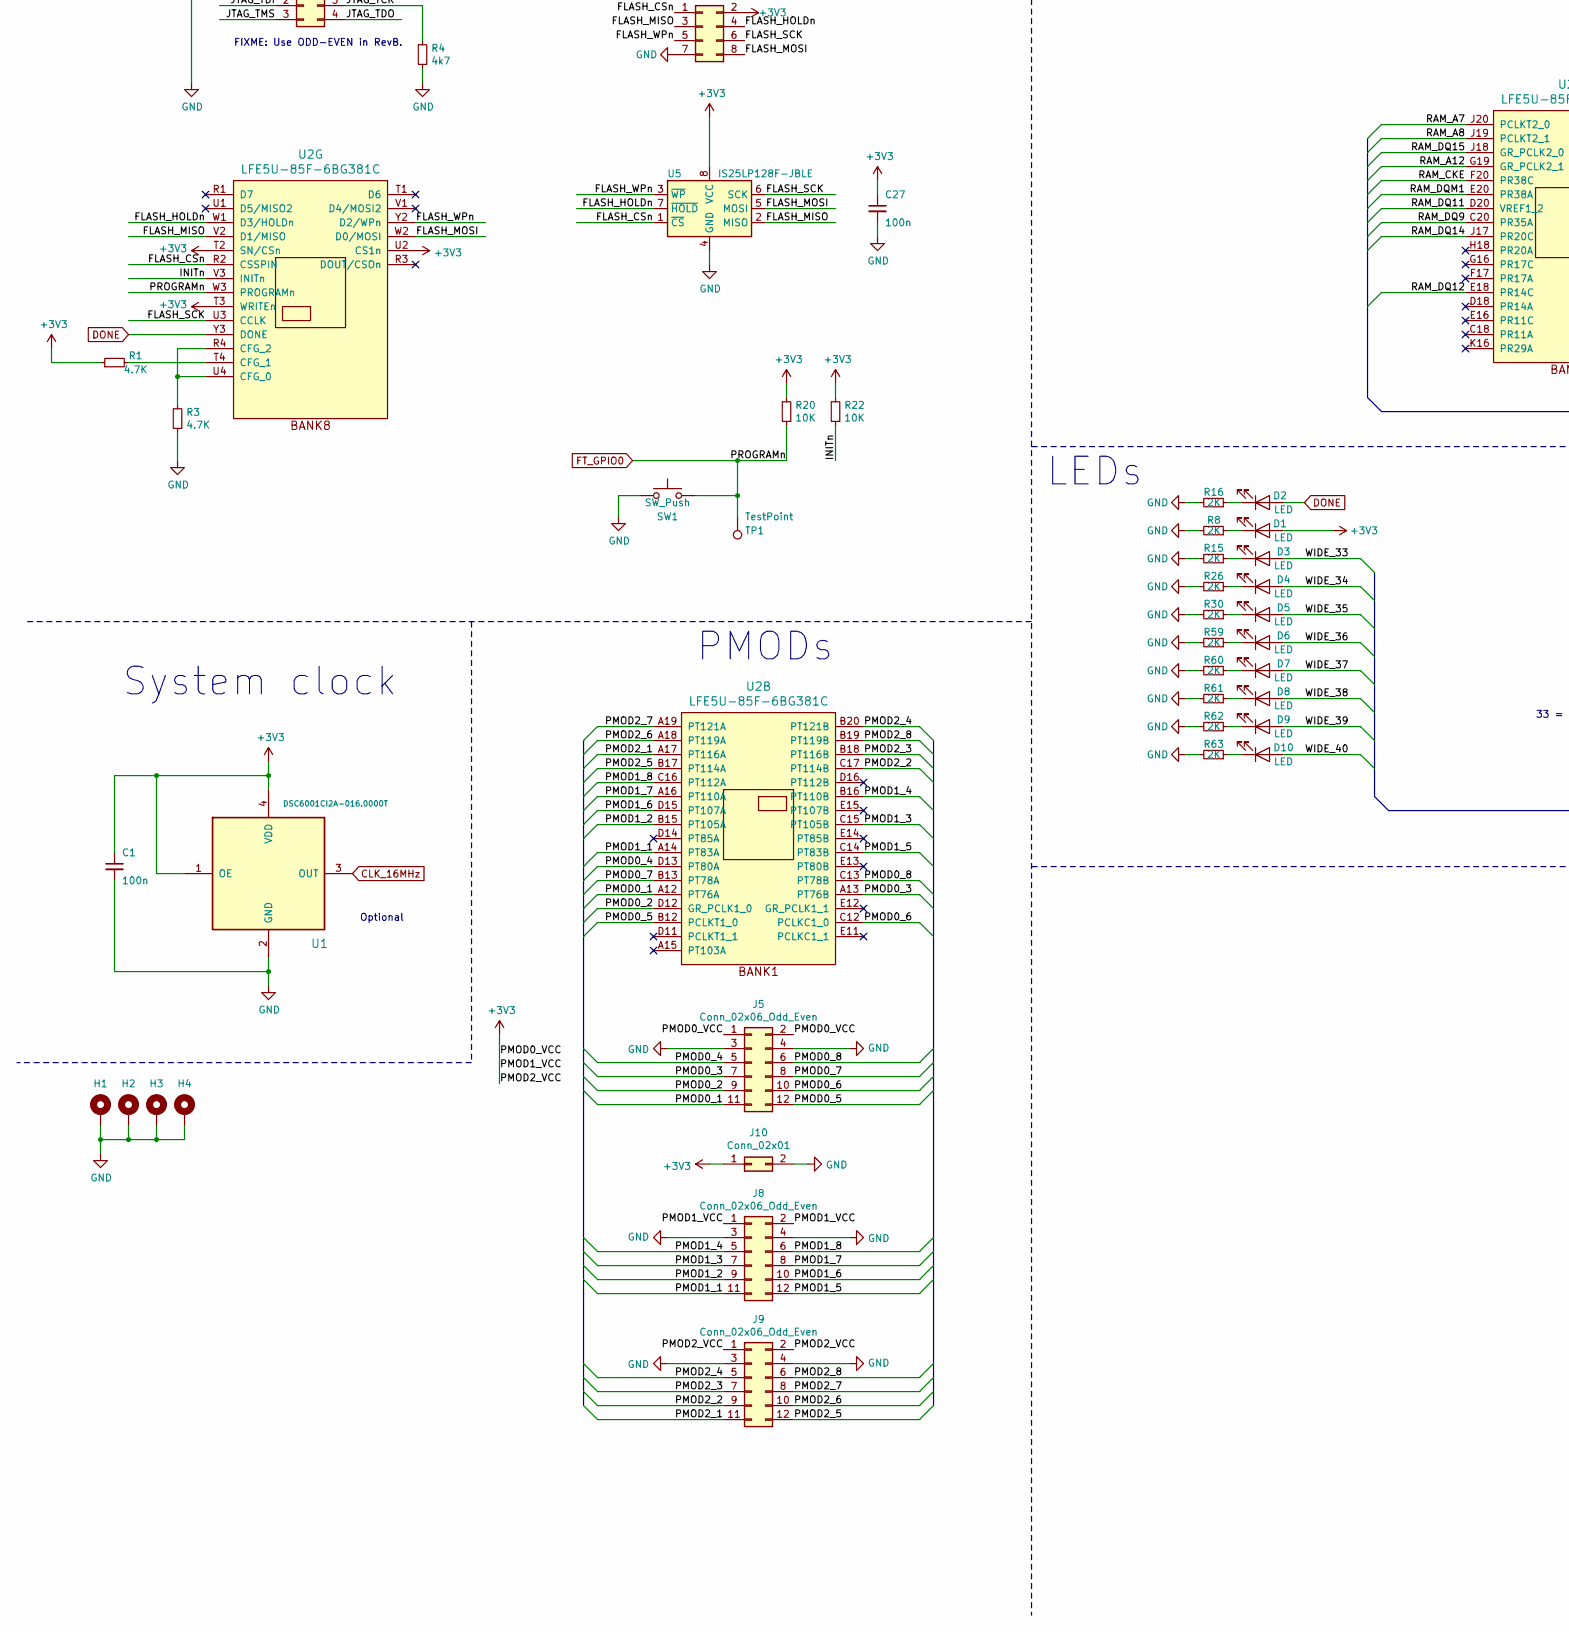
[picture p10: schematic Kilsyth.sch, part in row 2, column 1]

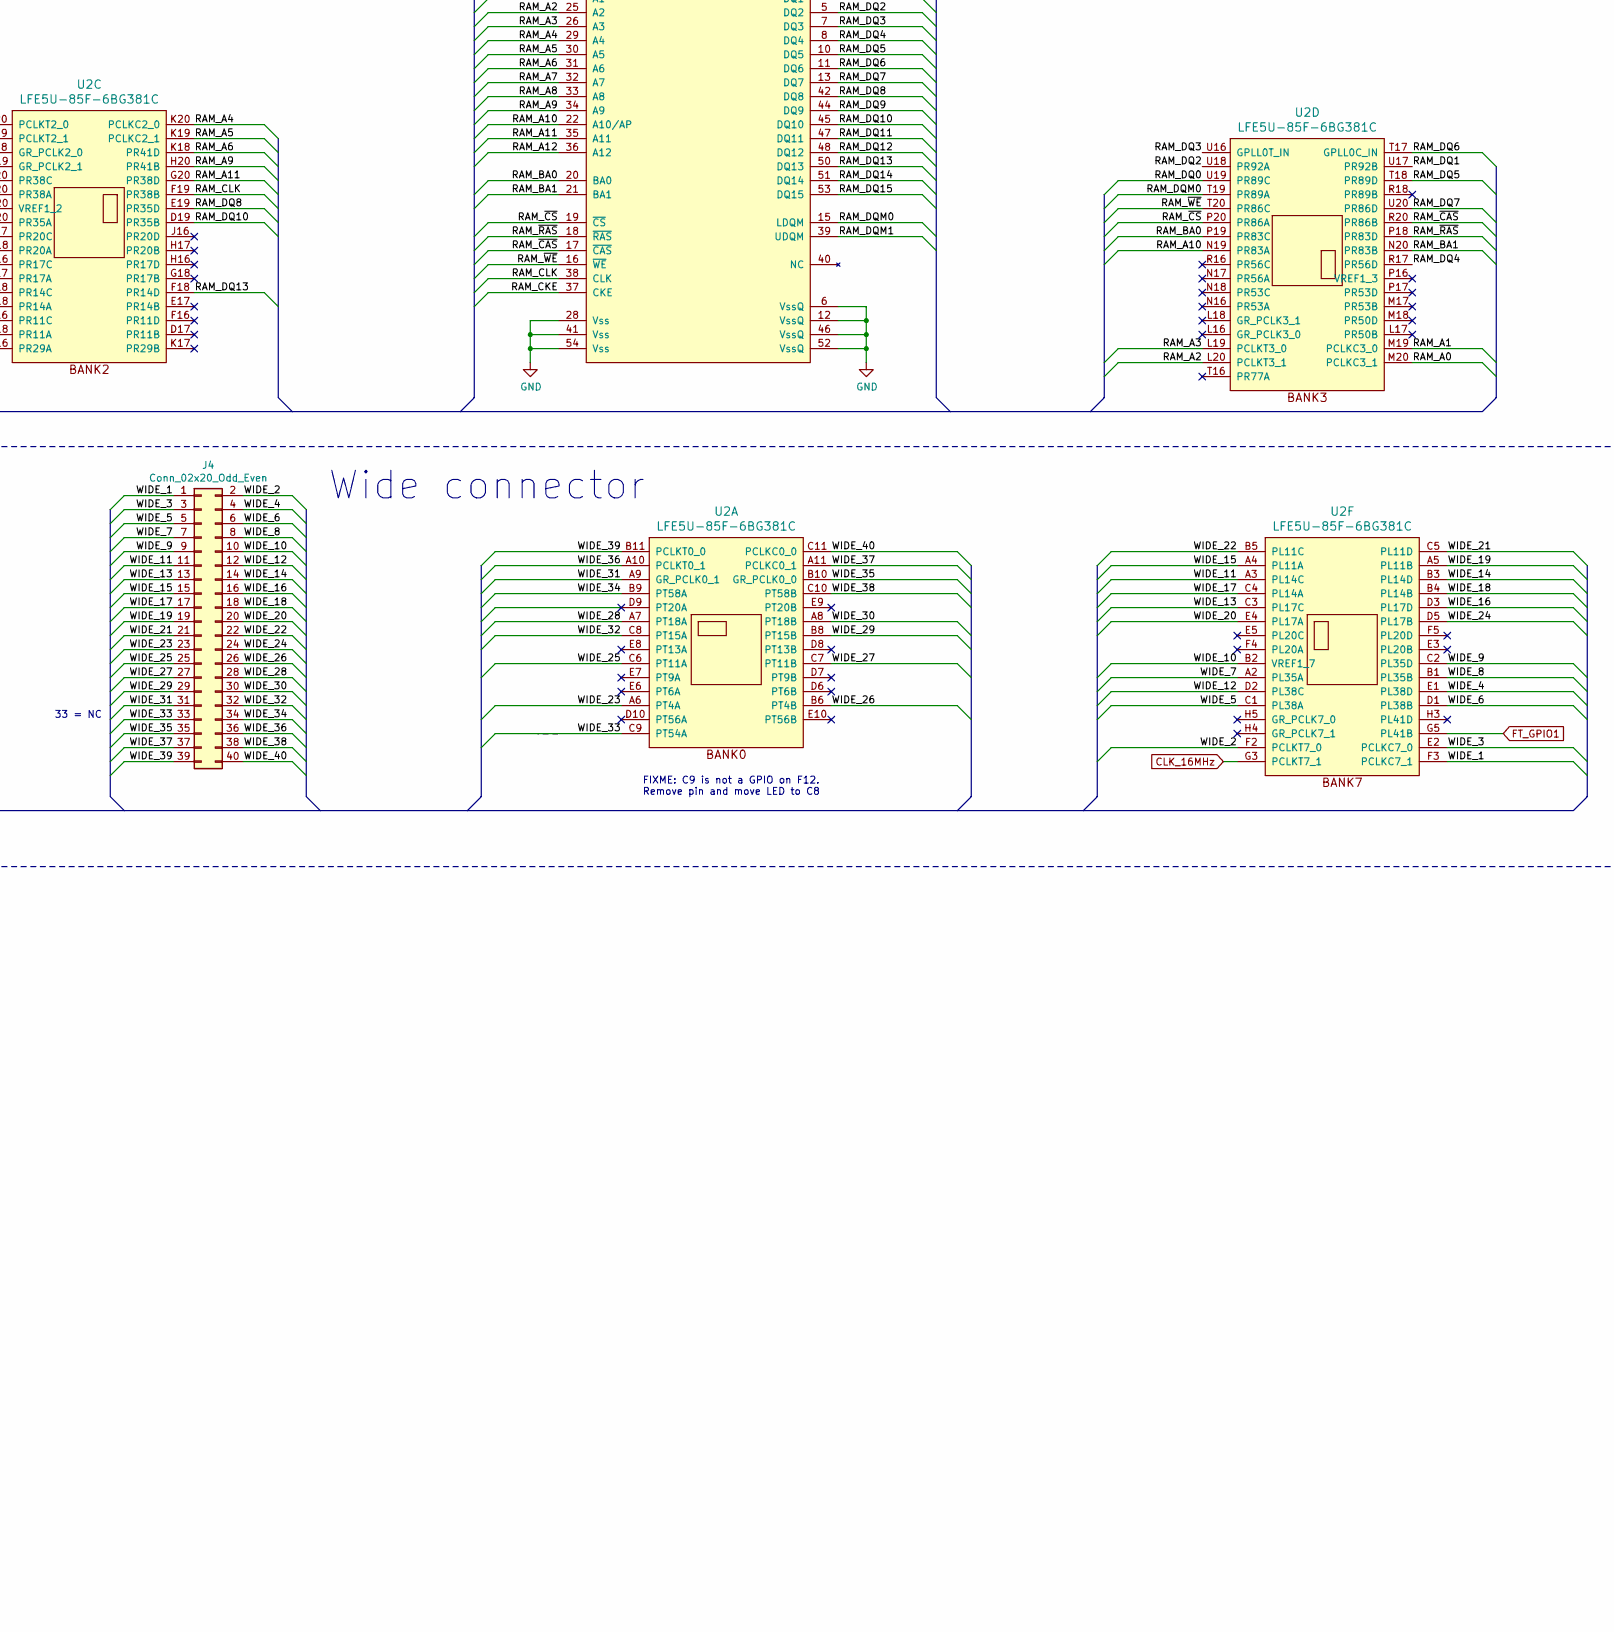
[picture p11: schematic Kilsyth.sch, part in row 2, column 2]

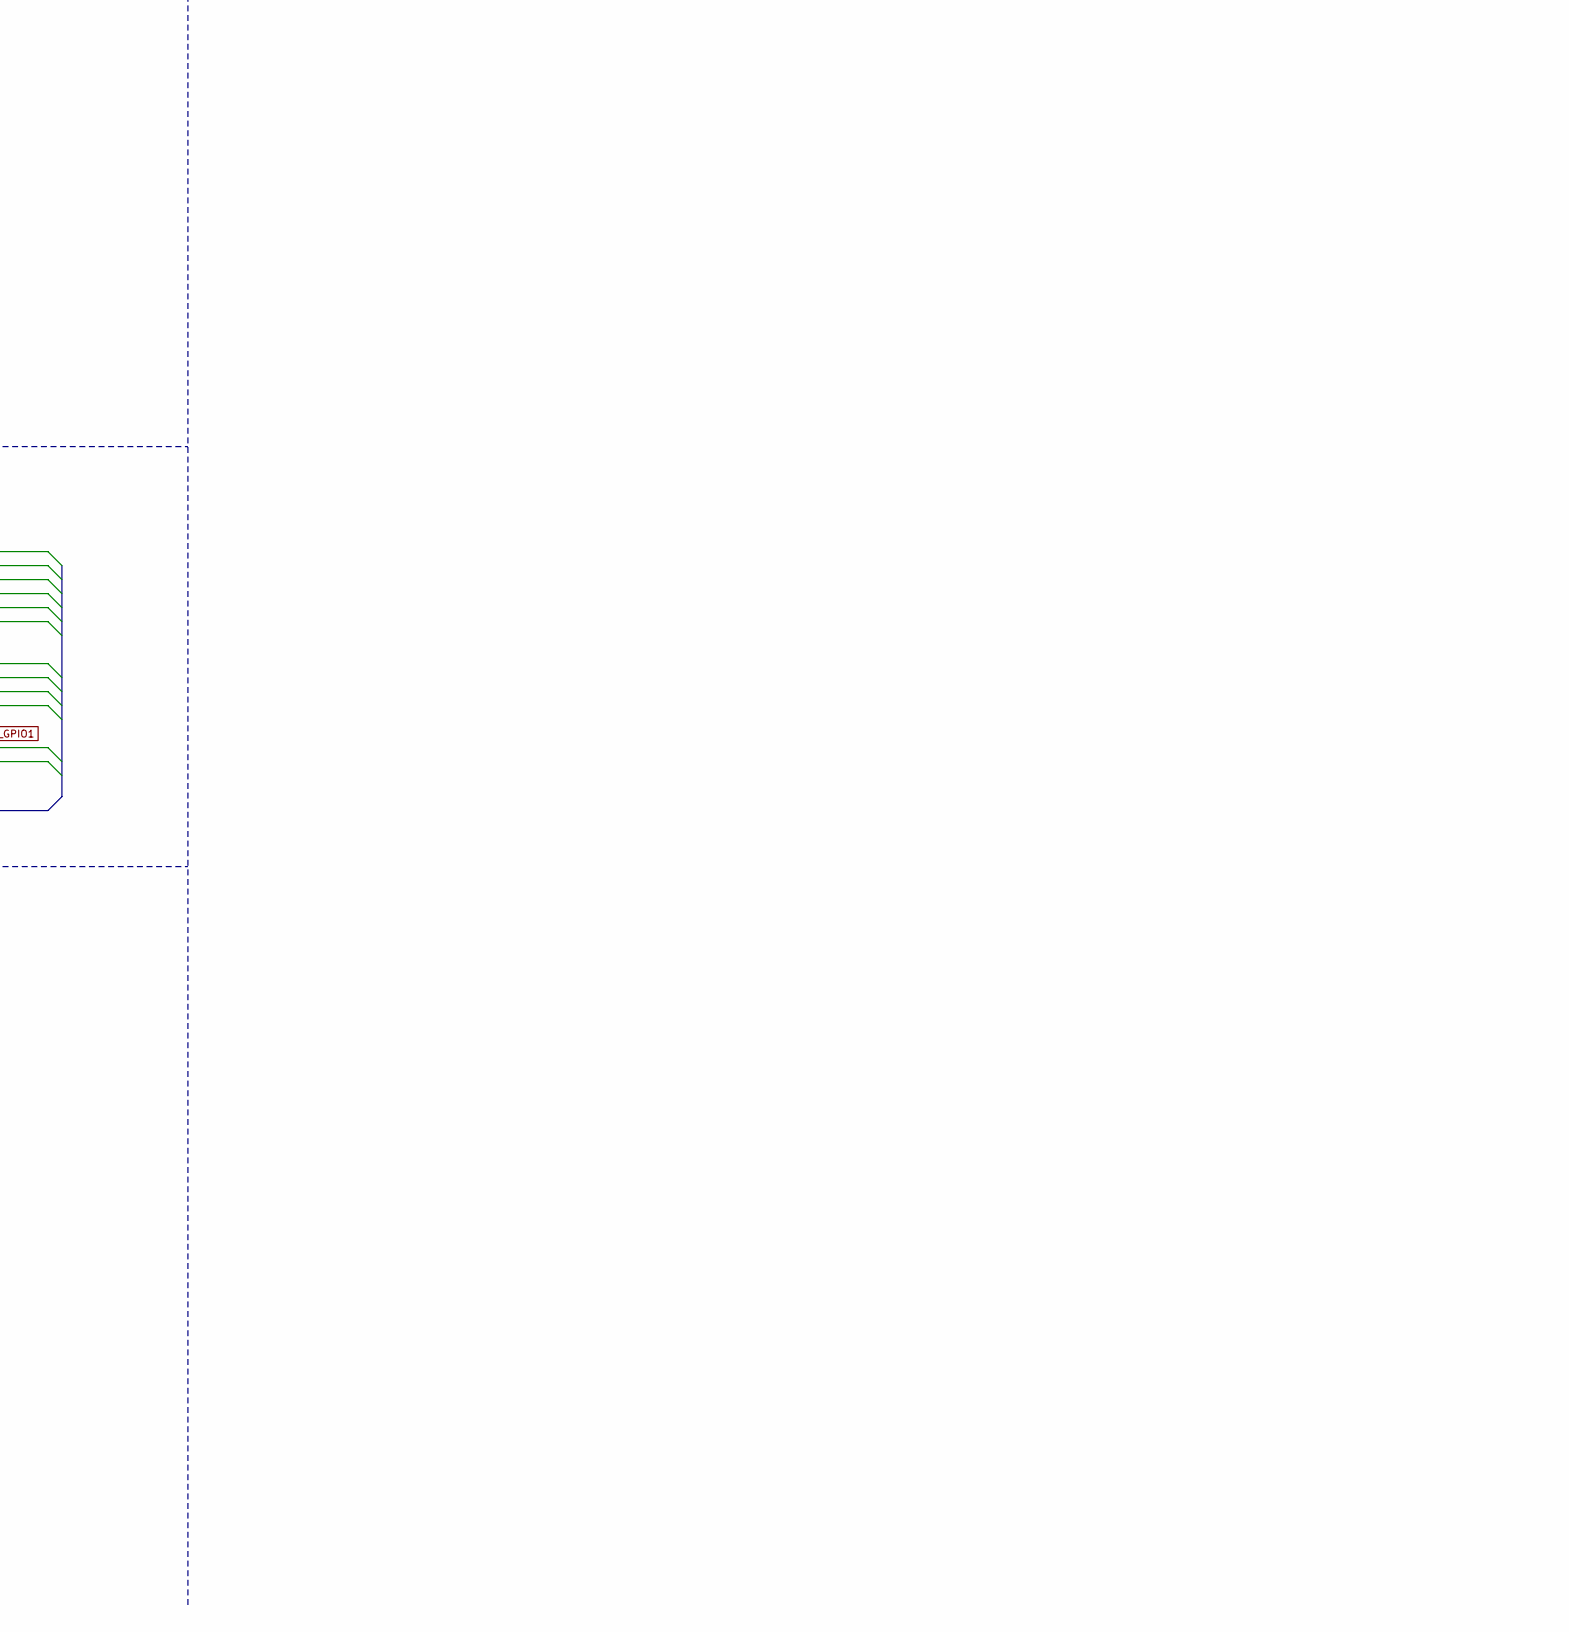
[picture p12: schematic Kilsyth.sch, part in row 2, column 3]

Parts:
C1, C6, C27, C30, C31, C35, C36, C37, C39, C40, C41, C42, C44, C45, C46, C50, C51, C54, C55, C58, C60, C62, C64, C66: 100n; C_0603_1608Metric
C2: 1u; C_0603_1608Metric
C3, C4, C5: 10u; C_0603_1608Metric
C8, C9, C10, C47, C48, C49, C52, C53, C56, C57, C59, C61, C63, C65, C67: 10n; C_0603_1608Metric
C11, C12, C13, C20, C21, C22: 22p; C_0603_1608Metric
C14, C15, C16: 47n; C_0603_1608Metric
C17, C18, C19: 3.3n; C_0603_1608Metric
C23, C24, C25, C26: 22u; C_0603_1608Metric
C32, C38, C43: 4u7; C_0603_1608Metric
C33, C34: 18p; C_0603_1608Metric
D1, D2, D3, D4, D5, D6, D7, D8, D9, D10: LED; LED_0603_1608Metric
FB1: Ferrite_Bead; L_0603_1608Metric
H1, H2, H3, H4: MountingHole_3.2mm_M3_Pad
J1: Conn_JTAG; PinHeader_2x03_P2.54mm_Vertical_SMD
J2: DX07S024JJ2; USBC_DX07S024JJ2R1300; Mouser 656-DX07S024JJ2R1300
J3: USB_B_Micro; USB_Micro-B_Molex-105017-0001
J4: Conn_02x20_Odd_Even; PinHeader_2x20_P2.54mm_Vertical_SMD
J5, J8, J9: Conn_02x06_Odd_Even; PinSocket_2x06_P2.54mm_Horizontal
J6, J7: PUSB3FR4Z; Mouser 771-PUSB3FR4Z
J10: Conn_02x01; PinHeader_2x01_P2.54mm_Vertical
J11, J12: Conn_02x04_Odd_Even; PinHeader_2x04_P2.54mm_Vertical_SMD
L1, L2, L3: 2.2u; L_1008_1210; Mouser 81-DFE322512F-2R2MP2
R1, R3, R12: 4.7K; R_0603_1608Metric
R2: 73.2K; R_0603_1608Metric
R4: 4k7; R_0603_1608Metric
R5, R6, R7: 20K; R_0603_1608Metric
R8, R15, R16, R26, R30, R59, R60, R61, R62, R63: 2K; R_0603_1608Metric
R9, R11, R13: 15K; R_0603_1608Metric
R10: 18K; R_0603_1608Metric
R14: 3.3K; R_0603_1608Metric
R17, R18, R21, R23, R24, R27, R28, R29, R35, R36, R37, R38, R39, R40, R41, R42, R43, R44, R45, R46, R47, R48, R49, R50, R51, R52, R53, R54, R55, R56, R57, R58: 0R; R_0603_1608Metric
R20, R22, R32, R33, R34: 10K; R_0603_1608Metric
R25: 5K1; R_0603_1608Metric
R31: 1.6K; R_0603_1608Metric
SW1: SW_Push; SmallButton
TP1, TP2, TP3, TP5: TestPoint; TestPoint_Pad_D1.0mm
U1: DSC6001CI2A-016.0000T; Crystal_SMD_3225-4Pin_3.2x2.5mm; Mouser 579-6001CI2A0160000T
U2: LFE5U-85F-6BG381C; BGA-381_pitch0.8mm_dia0.4mm
U3: TPS65261; S-PVQFN-N32; Mouser 595-TPS65261RHBR
U5: IS25LP128F-JBLE; SOA008-150-208mil; Mouser 870-IS25LP128F-JBLE
U6: FT600Q; QFN-56-1EP_7x7mm_P0.4mm_EP5.7x5.7mm_FIXED; Mouser 895-FT600Q-B-T
U7: AS4C32M16SB; TSOP-II-54_22.2x10.16mm_P0.8mm
Y1: 30MHz ±20ppm; Crystal_SMD_2016-4Pin_2.0x1.6mm; Part number XRCPB30M000F2P00R0

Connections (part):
+1V1: C44.1, C47.1, C50.1, C52.1, C54.1, C56.1, R21.1, TP5.1, U2.H8 (VCC), U2.H9 (VCC), U2.H10 (VCC), U2.H11 (VCC), U2.H12 (VCC), U2.H13 (VCC), U2.J8 (VCC), U2.J13 (VCC), U2.K8 (VCC), U2.K13 (VCC), U2.L8 (VCC), U2.L13 (VCC), U2.M8 (VCC), U2.M13 (VCC), U2.N8 (VCC), U2.N9 (VCC), U2.N10 (VCC), U2.N11 (VCC), U2.N12 (VCC), U2.N13 (VCC)
+2V5: C6.1, C45.1, C48.1, R17.1, TP2.1, U2.F6 (VCCAUX), U2.F15 (VCCAUX), U2.P6 (VCCAUX), U2.P15 (VCCAUX)
+3V3: C1.1, C27.1, C32.1, C35.1, C36.1, C39.1, C40.1, C41.1, C42.1, C43.1, C46.1, C49.1, C51.1, C53.1, C55.1, C57.1, C58.1, C59.1, C60.1, C61.1, C62.1, C63.1, C64.1, C65.1, C66.1, C67.1, D1.2 (A), J1.6, J5.1, J5.2, J8.1, J8.2, J9.1, J9.2, J10.1, J11.2, J12.2, J12.4, J12.6, J12.8, R1.1, R18.1, R20.2, R22.2, R32.2, R33.2, R34.2, TP3.1, U1.1 (OE), U1.4 (VDD), U2.F9 (VCCio0), U2.F10 (VCCio0), U2.F11 (VCCio1), U2.F12 (VCCio1), U2.H6 (VCCio7), U2.H7 (VCCio7), U2.H14 (VCCio2), U2.H15 (VCCio2), U2.J6 (VCCio7), U2.J15 (VCCio2), U2.L6 (VCCio6), U2.L7 (VCCio6), U2.L14 (VCCio3), U2.L15 (VCCio3), U2.M6 (VCCio6), U2.M15 (VCCio3), U2.P9 (VCCio8), U2.P10 (VCCio8), U2.T2 (SN/CSn), U2.T3 (WRITEn), U2.U2 (CS1n), U5.8 (VCC), U6.15 (VCC33), U6.19 (VCC33), U6.22 (VDDA), U6.30 (VCC33), U6.38 (VCCIO), U6.44 (VCCIO), U6.52 (VCCIO), U7.1 (Vdd), U7.3 (VddQ)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
+5V: C3.1, C4.1, C5.1, FB1.1, U3.12 (PVIN2), U3.13 (PVIN3), U3.28 (PVIN1), U3.29 (VIN), U6.29 (VBUS)
/FLASH_CSn: J11.1, U2.R2 (CSSPIN), U5.1 (~CS)
/FLASH_HOLDn: J11.4, U2.W1 (D3/HOLDn), U5.7 (~HOLD)
/FLASH_MISO: J11.3, U2.V2 (D1/MISO), U5.2 (MISO)
/FLASH_MOSI: J11.8, U2.W2 (D0/MOSI), U5.5 (MOSI)
/FLASH_SCK: J11.6, U2.U3 (CCLK), U5.6 (SCK)
/FLASH_WPn: J11.5, U2.Y2 (D2/WPn), U5.3 (~WP)
/FT_BE_0: R41.1, U2.K1 (PL53D)
/FT_BE_1: R40.1, U2.J5 (PL50B)
/FT_CLK: R50.1, U2.M4 (PL83A)
/FT_DATA_0: R58.1, U2.P4 (GPLL0C_IN)
/FT_DATA_1: R57.1, U2.P3 (GPLL0T_IN)
/FT_DATA_2: R56.1, U2.P2 (PL92B)
/FT_DATA_3: R55.1, U2.P1 (PL92A)
/FT_DATA_4: R54.1, U2.N4 (PL83C)
/FT_DATA_5: R53.1, U2.N3 (PL86A)
/FT_DATA_6: R52.1, U2.N2 (PL65A)
/FT_DATA_7: R51.1, U2.N1 (PL89D)
/FT_DATA_8: R49.1, U2.M3 (PL86B)
/FT_DATA_9: R48.1, U2.M1 (PL89B)
/FT_DATA_10: R47.1, U2.L3 (PL86C)
/FT_DATA_11: R46.1, U2.L2 (PL86D)
/FT_DATA_12: R45.1, U2.L1 (PL65C)
/FT_DATA_13: R44.1, U2.K4 (PL56A)
/FT_DATA_14: R43.1, U2.K3 (PL50D)
/FT_DATA_15: R42.1, U2.K2 (PL53A)
/FT_DM: J6.2, J6.9, R27.1, U6.20 (DM)
/FT_DP: J6.1, J6.10, R28.1, U6.18 (DP)
/FT_OE_N: R35.1, U2.H1 (PL53C)
/FT_RD_N: R36.1, U2.H2 (PCLKT6_0)
/FT_RIDN: J2.B10 (RX1-), J7.1, J7.10, U6.27 (RIDN)
/FT_RIDP: J2.B11 (RX1+), J7.2, J7.9, U6.28 (RIDP)
/FT_RXF_N: R38.1, U2.J3 (GR_PCLK6_1)
/FT_TODN: C30.2, J7.4, J7.7, U6.24 (TODN)
/FT_TODP: C31.2, J7.5, J7.6, U6.25 (TODP)
/FT_TXE_N: R39.1, U2.J4 (GR_PCLK6_0)
/FT_WR_N: R37.1, U2.J1 (PL53B)
/INITn: R22.1, U2.V3 (INITn)
/JTAG_TCK: J1.5, R4.1, U2.T5 (TCK)
/JTAG_TDI: J1.2, U2.R5 (TDI)
/JTAG_TDO: J1.4, U2.V4 (TDO)
/JTAG_TMS: J1.3, U2.U5 (TMS)
/PMOD0_1: J5.11, U2.A12 (PT76A)
/PMOD0_2: J5.9, U2.D12 (GR_PCLK1_0)
/PMOD0_3: J5.7, U2.A13 (PT76B)
/PMOD0_4: J5.5, U2.D13 (PT80A)
/PMOD0_5: J5.12, U2.B12 (PCLKT1_0)
/PMOD0_6: J5.10, U2.C12 (PCLKC1_0)
/PMOD0_7: J5.8, U2.B13 (PT78A)
/PMOD0_8: J5.6, U2.C13 (PT78B)
/PMOD1_1: J8.11, U2.A14 (PT83A)
/PMOD1_2: J8.9, U2.B15 (PT105A)
/PMOD1_3: J8.7, U2.C15 (PT105B)
/PMOD1_4: J8.5, U2.B16 (PT110B)
/PMOD1_5: J8.12, U2.C14 (PT83B)
/PMOD1_6: J8.10, U2.D15 (PT107A)
/PMOD1_7: J8.8, U2.A16 (PT110A)
/PMOD1_8: J8.6, U2.C16 (PT112A)
/PMOD2_1: J9.11, U2.A17 (PT116A)
/PMOD2_2: J9.9, U2.C17 (PT114B)
/PMOD2_3: J9.7, U2.B18 (PT116B)
/PMOD2_4: J9.5, U2.B20 (PT121B)
/PMOD2_5: J9.12, U2.B17 (PT114A)
/PMOD2_6: J9.10, U2.A18 (PT119A)
/PMOD2_7: J9.8, U2.A19 (PT121A)
/PMOD2_8: J9.6, U2.B19 (PT119B)
/RAM_A0: U2.M20 (PCLKC3_1), U7.23 (A0)
/RAM_A1: U2.M19 (PCLKC3_0), U7.24 (A1)
/RAM_A2: U2.L20 (PCLKT3_1), U7.25 (A2)
/RAM_A3: U2.L19 (PCLKT3_0), U7.26 (A3)
/RAM_A4: U2.K20 (PCLKC2_0), U7.29 (A4)
/RAM_A5: U2.K19 (PCLKC2_1), U7.30 (A5)
/RAM_A6: U2.K18 (PR41D), U7.31 (A6)
/RAM_A7: U2.J20 (PCLKT2_0), U7.32 (A7)
/RAM_A8: U2.J19 (PCLKT2_1), U7.33 (A8)
/RAM_A9: U2.H20 (PR41B), U7.34 (A9)
/RAM_A10: U2.N19 (PR83A), U7.22 (A10/AP)
/RAM_A11: U2.G20 (PR38D), U7.35 (A11)
/RAM_A12: U2.G19 (GR_PCLK2_1), U7.36 (A12)
/RAM_BA0: U2.P19 (PR83C), U7.20 (BA0)
/RAM_BA1: U2.N20 (PR83B), U7.21 (BA1)
/RAM_CKE: U2.F20 (PR38C), U7.37 (CKE)
/RAM_CLK: U2.F19 (PR38B), U7.38 (CLK)
/RAM_DQ0: U2.U19 (PR89C), U7.2 (DQ0)
/RAM_DQ1: U2.U17 (PR92B), U7.4 (DQ1)
/RAM_DQ2: U2.U18 (PR92A), U7.5 (DQ2)
/RAM_DQ3: U2.U16 (GPLL0T_IN), U7.7 (DQ3)
/RAM_DQ4: U2.R17 (PR56D), U7.8 (DQ4)
/RAM_DQ5: U2.T18 (PR89D), U7.10 (DQ5)
/RAM_DQ6: U2.T17 (GPLL0C_IN), U7.11 (DQ6)
/RAM_DQ7: U2.U20 (PR86D), U7.13 (DQ7)
/RAM_DQ8: U2.E19 (PR35D), U7.42 (DQ8)
/RAM_DQ9: U2.C20 (PR35A), U7.44 (DQ9)
/RAM_DQ10: U2.D19 (PR35B), U7.45 (DQ10)
/RAM_DQ11: U2.D20 (VREF1_2), U7.47 (DQ11)
/RAM_DQ12: U2.E18 (PR14C), U7.48 (DQ12)
/RAM_DQ13: U2.F18 (PR14D), U7.50 (DQ13)
/RAM_DQ14: U2.J17 (PR20C), U7.51 (DQ14)
/RAM_DQ15: U2.J18 (GR_PCLK2_0), U7.53 (DQ15)
/RAM_DQM0: U2.T19 (PR89A), U7.15 (LDQM)
/RAM_DQM1: U2.E20 (PR38A), U7.39 (UDQM)
/RAM_~CAS: U2.R20 (PR86B), U7.17 (~CAS)
/RAM_~CS: U2.P20 (PR86A), U7.19 (~CS)
/RAM_~RAS: U2.P18 (PR83D), U7.18 (~RAS)
/RAM_~WE: U2.T20 (PR86C), U7.16 (~WE)
/USB_DM: J2.A7 (D-), J3.2 (D-), R27.2
/USB_DP: J2.A6 (D+), J3.3 (D+), R28.2
/USB_TXN: C30.1, J2.A3 (TX1-)
/USB_TXP: C31.1, J2.A2 (TX1+)
/WIDE_1: J4.1, U2.F3 (PCLKC7_1)
/WIDE_2: J4.2, U2.F2 (PCLKT7_0)
/WIDE_3: J4.3, U2.E2 (PCLKC7_0)
/WIDE_4: J4.4, U2.E1 (PL38D)
/WIDE_5: J4.5, U2.C1 (PL38A)
/WIDE_6: J4.6, U2.D1 (PL38B)
/WIDE_7: J4.7, U2.A2 (PL35A)
/WIDE_8: J4.8, U2.B1 (PL35B)
/WIDE_9: J4.9, U2.C2 (PL35D)
/WIDE_10: J4.10, U2.B2 (VREF1_7)
/WIDE_11: J4.11, U2.A3 (PL14C)
/WIDE_12: J4.12, U2.D2 (PL38C)
/WIDE_13: J4.13, U2.C3 (PL17C)
/WIDE_14: J4.14, U2.B3 (PL14D)
/WIDE_15: J4.15, U2.A4 (PL11A)
/WIDE_16: J4.16, U2.D3 (PL17D)
/WIDE_17: J4.17, U2.C4 (PL14A)
/WIDE_18: J4.18, U2.B4 (PL14B)
/WIDE_19: J4.19, U2.A5 (PL11B)
/WIDE_20: J4.20, U2.E4 (PL17A)
/WIDE_21: J4.21, U2.C5 (PL11D)
/WIDE_22: J4.22, U2.B5 (PL11C)
/WIDE_23: J4.23, U2.A6 (PT4A)
/WIDE_24: J4.24, U2.D5 (PL17B)
/WIDE_25: J4.25, U2.C6 (PT11A)
/WIDE_26: J4.26, U2.B6 (PT4B)
/WIDE_27: J4.27, U2.C7 (PT11B)
/WIDE_28: J4.28, U2.A7 (PT18A)
/WIDE_29: J4.29, U2.B8 (PT15B)
/WIDE_30: J4.30, U2.A8 (PT18B)
/WIDE_31: J4.31, U2.A9 (GR_PCLK0_1)
/WIDE_32: J4.32, U2.C8 (PT15A)
/WIDE_33: D3.2 (A), J4.33, U2.C9 (PT54A)
/WIDE_34: D4.2 (A), J4.34, U2.B9 (PT58A)
/WIDE_35: D5.2 (A), J4.35, U2.B10 (GR_PCLK0_0)
/WIDE_36: D6.2 (A), J4.36, U2.A10 (PCLKT0_1)
/WIDE_37: D7.2 (A), J4.37, U2.A11 (PCLKC0_1)
/WIDE_38: D8.2 (A), J4.38, U2.C10 (PT58B)
/WIDE_39: D9.2 (A), J4.39, U2.B11 (PCLKT0_0)
/WIDE_40: D10.2 (A), J4.40, U2.C11 (PCLKC0_0)
CLK_16MHz: U1.3 (OUT), U2.G3 (PCLKT7_1)
DONE: D2.2 (A), U2.Y3 (DONE)
FT_GPIO0: R20.1, R24.2, SW1.2, TP1.1, U2.W3 (PROGRAMn)
FT_GPIO1: R23.2, U2.G5 (PL41B)
GND: C1.2, C2.2, C3.2, C4.2, C5.2, C6.2, C8.2, C9.2, C10.2, C11.2, C12.2, C13.2, C17.2, C18.2, C19.2, C23.2, C24.2, C25.2, C26.2, C27.2, C32.2, C33.1, C34.1, C35.2, C36.2, C37.2, C38.2, C39.2, C40.2, C41.2, C42.2, C43.2, C44.2, C45.2, C46.2, C47.2, C48.2, C49.2, C50.2, C51.2, C52.2, C53.2, C54.2, C55.2, C56.2, C57.2, C58.2, C59.2, C60.2, C61.2, C62.2, C63.2, C64.2, C65.2, C66.2, C67.2, H1.1, H2.1, H3.1, H4.1, J1.1, J2.A1 (GND), J2.A12 (GND), J2.B1 (GND), J2.B12 (GND), J2.S1 (SHIELD), J3.5 (GND), J3.6 (Shield), J5.3, J5.4, J6.3, J6.8, J7.3, J7.8, J8.3, J8.4, J9.3, J9.4, J10.2, J11.7, J12.1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
unnamed: C2.1, U3.4 (MODE), U3.5 (V7V)
unnamed: C8.1, U3.24 (SS1)
unnamed: C9.1, U3.8 (SS2)
unnamed: C10.1, U3.17 (SS3)
unnamed: C11.1, R5.1, U3.23 (COMP1)
unnamed: C12.1, R6.1, U3.7 (COMP2)
unnamed: C13.1, R7.1, U3.18 (COMP3)
unnamed: C14.1, U3.25 (BST1)
unnamed: C14.2, L1.1, U3.26 (LX1)
unnamed: C15.1, U3.9 (BST2)
unnamed: C15.2, L2.1, U3.10 (LX2)
unnamed: C16.1, U3.16 (BST3)
unnamed: C16.2, L3.1, U3.15 (LX3)
unnamed: C17.1, R5.2
unnamed: C18.1, R6.2
unnamed: C19.1, R7.2
unnamed: C20.1, C23.1, C26.1, L1.2, R9.1, R21.2
unnamed: C20.2, R9.2, R10.1, U3.22 (FB1)
unnamed: C21.1, C24.1, L2.2, R11.1, R17.2
unnamed: C21.2, R11.2, R12.1, U3.6 (FB2)
unnamed: C22.1, C25.1, L3.2, R13.1, R18.2
unnamed: C22.2, R13.2, R14.1, U3.19 (FB3)
unnamed: C33.2, U6.16 (XI), Y1.1
unnamed: C34.2, U6.17 (XO), Y1.3
unnamed: D1.1 (K), R8.1
unnamed: D2.1 (K), R16.1
unnamed: D3.1 (K), R15.1
unnamed: D4.1 (K), R26.1
unnamed: D5.1 (K), R30.1
unnamed: D6.1 (K), R59.1
unnamed: D7.1 (K), R60.1
unnamed: D8.1 (K), R61.1
unnamed: D9.1 (K), R62.1
unnamed: D10.1 (K), R63.1
unnamed: J2.A5 (CC1), R25.2
unnamed: J2.A8 (SBU1), R29.2
unnamed: R1.2, U2.T4 (CFG_1)
unnamed: R2.1, U3.20 (ROSC)
unnamed: R3.2, U2.R4 (CFG_2), U2.U4 (CFG_0)
unnamed: R23.1, U6.13 (GPIO1)
unnamed: R24.1, U6.12 (GPIO0)
unnamed: R31.1, U6.21 (RREF)
unnamed: R32.1, U6.6 (SIWU_N)
unnamed: R33.1, U6.10 (RESET_N)
unnamed: R34.1, U6.11 (WAKEUP_N)
unnamed: R35.2, U6.9 (OE_N)
unnamed: R36.2, U6.8 (RD_N)
unnamed: R37.2, U6.7 (WR_N)
unnamed: R38.2, U6.5 (RXF_N)
unnamed: R39.2, U6.4 (TXE_N)
unnamed: R40.2, U6.3 (BE_1)
unnamed: R41.2, U6.2 (BE_0)
unnamed: R42.2, U6.56 (DATA_15)
unnamed: R43.2, U6.55 (DATA_14)
unnamed: R44.2, U6.54 (DATA_13)
unnamed: R45.2, U6.53 (DATA_12)
unnamed: R46.2, U6.48 (DATA_11)
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

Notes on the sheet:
Ra = Rb * (0.6 / (Vout - 0.6)) Vout = (1 + 15e3/18e3) * 0.6 = 1.1V
Ra = Rb * (0.6 / (Vout - 0.6)) Vout = (1 + 15e3/4.7e3) * 0.6 = 2.51V
Ra = Rb * (0.6 / (Vout - 0.6)) Vout = (1 + 15e3/3.3e3) * 0.6 = 3.33V
RESET, PGOOD and VDIV can be left NC since we don't need those features. ENx is open drain. NC = enabled.
3.3V rail. Max 2A
1.8V rail. Max 300mA
2.5V rail. Max 2A
1.1V rail. Max 3A
No idea if these are needed so let's have 0R so we can patch it later.
Design goals: - High speed transfers with the FT600. Should reach 190MB/s theoretically with 16 bit @ 100MHz. - Should work with any variant of LFE5U, i.e. 12F, 25F, 45F, 85F. - Low cost BOM. Ideally <$25 for everything. - Loads bitstream from flash - JTAG should work - Bootloader on flash that all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
Voltage regulators
USB and FT600
JTAG and Flash
FPGA Power
System clock
LEDs
Optional
SDRAM
FT600
ROSC sets the switching frequency. 73.2K = 600kHz. Lower R -> higher f
One pair per bank
(KiCad bug, should use VBus but can't)
NON-reversible implementation. Sorry for that but it's too expensive.
TODO: Add 1V8 rail
ERRATA RevA
- C9 is not a GPIO on ECP5 F12 and some other variants. - FT_CLK is not routed to a clock pin. Can be fixed with a bodge wire on RevA! (R50 <-> R36) - JTAG connector has a funky footprint on the PCB because CCW vs Odd/Even pinout on the symbol vs footprint. PCB silk screen is accurate so don't worr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
FIXME: C9 is not a GPIO on F12. Remove pin and move LED to C8
33 = NC
BODGE: swap FT_RD_N with FT_CLK (R50 <-> R36) TODO: Route FT_CLK to a clock pin *sigh*
PMODs
Wide connector
FIXME: Use ODD-EVEN in RevB.

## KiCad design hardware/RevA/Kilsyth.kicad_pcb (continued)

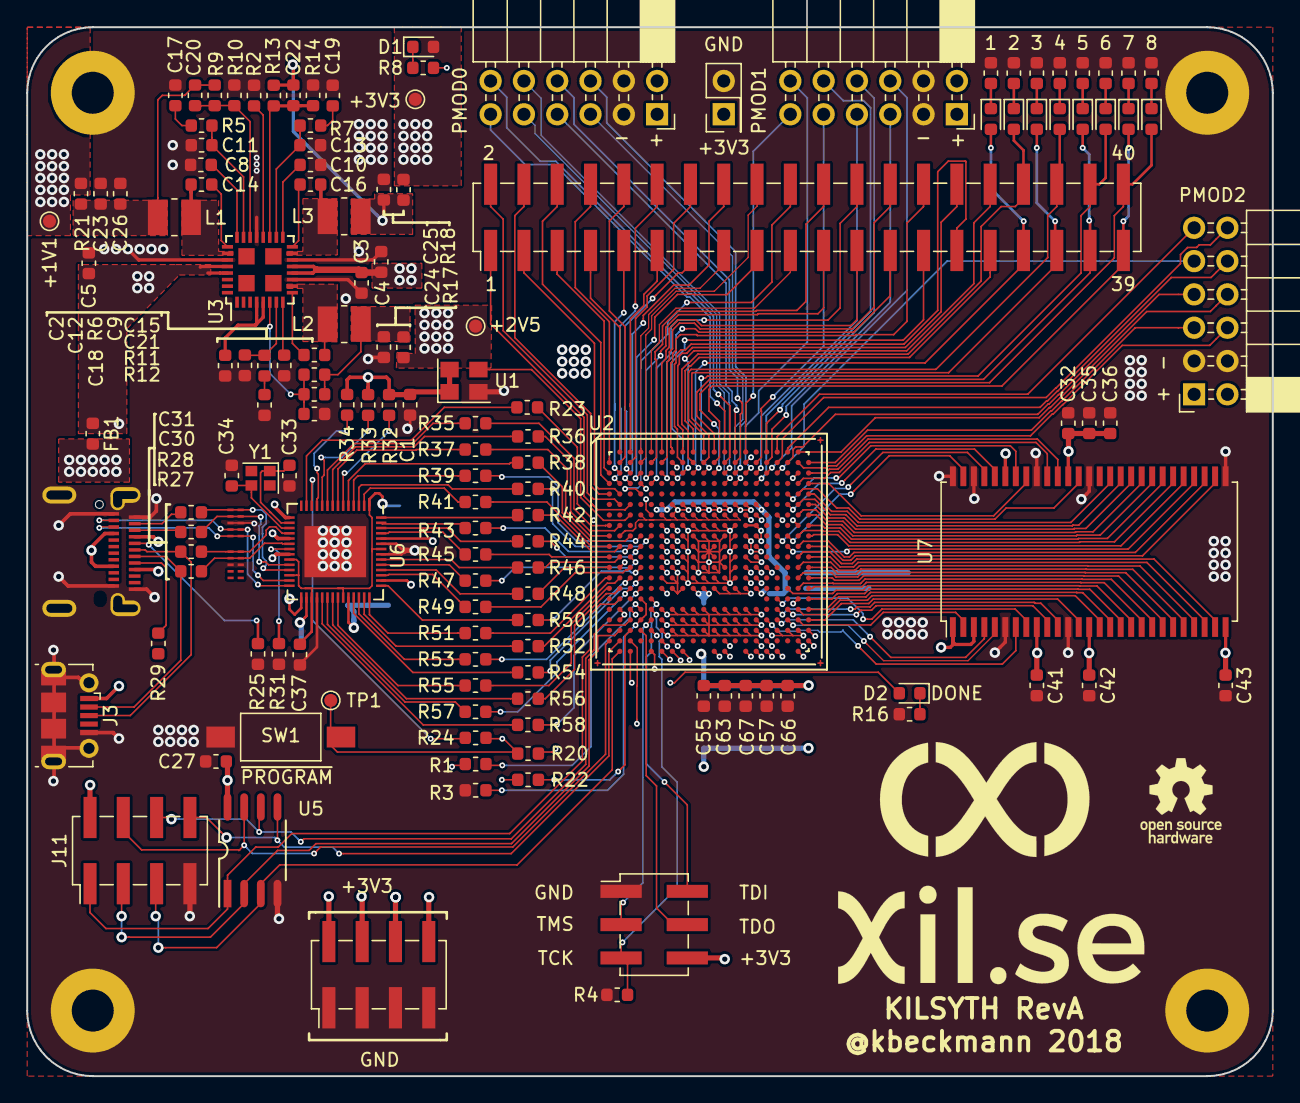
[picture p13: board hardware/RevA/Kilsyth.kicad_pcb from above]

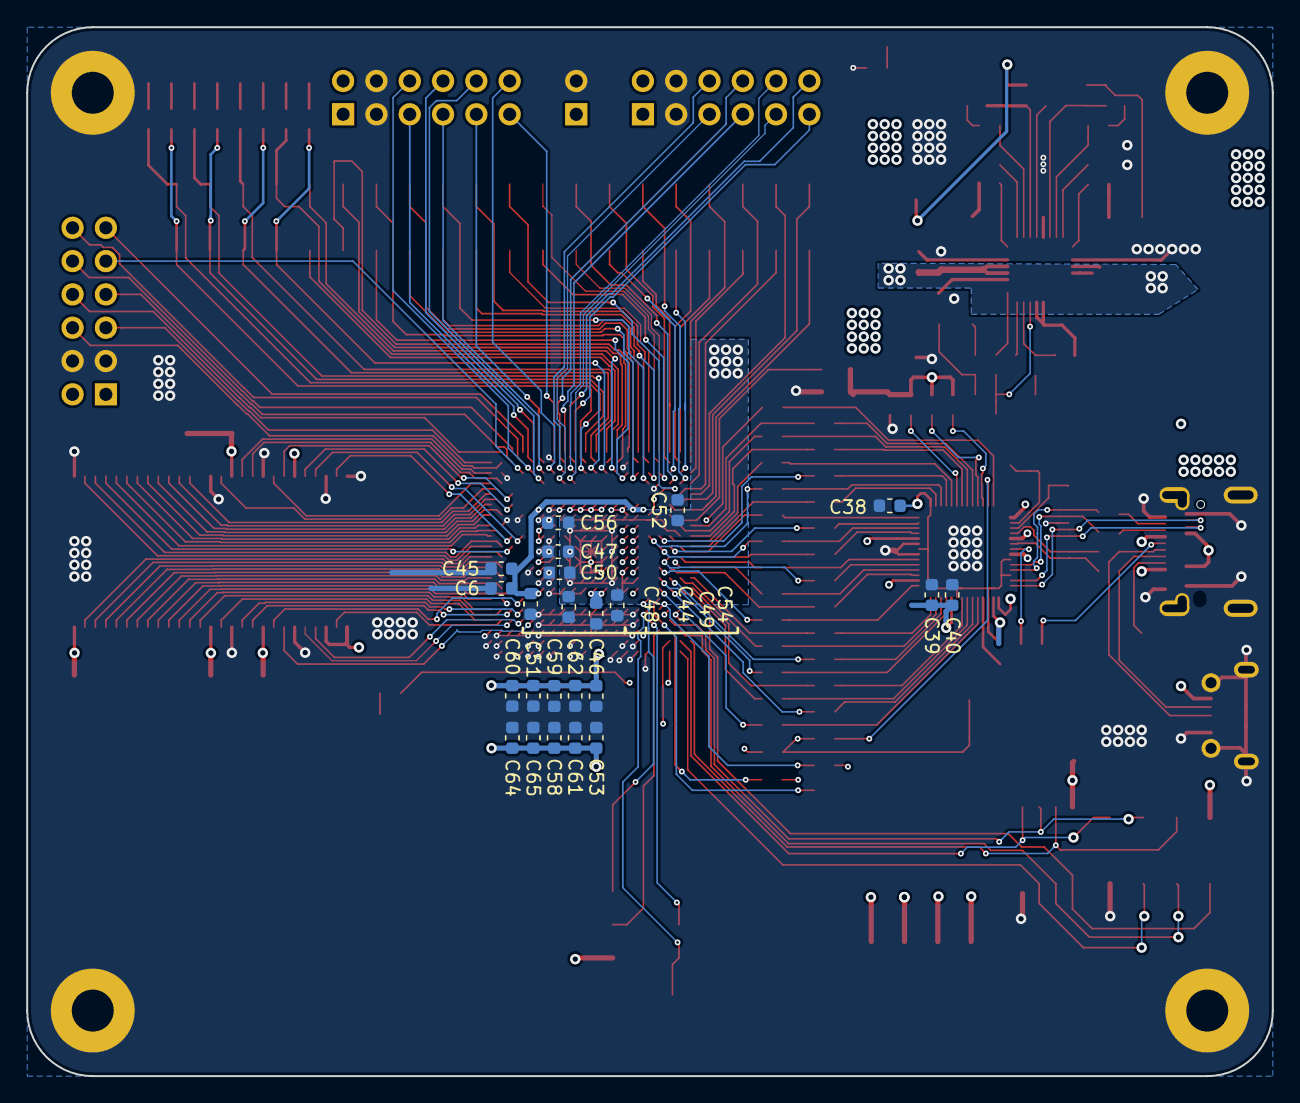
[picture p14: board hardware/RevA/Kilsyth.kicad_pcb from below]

Board: 4 copper layers, 95.0 x 80.0 mm, 168 parts (23 on the bottom side), 228 nets.

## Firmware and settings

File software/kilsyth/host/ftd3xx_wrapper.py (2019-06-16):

import sys
import time

from ..ftd3xx import ftd3xx
from ..ftd3xx.defines import *

class FTD3xxWrapper():
    def __init__(self):
        self.ResetChipConfiguration()

        channel = 0
        if sys.platform == 'linux':
            epout = channel
            epin = channel
        else:
            epout = 0x02 + channel
            epin = 0x82 + channel

        D3XX = ftd3xx.create(0, FT_OPEN_BY_INDEX)
        if D3XX is None:
            print("ERROR: Please check if another D3XX application is open!")
            return

        self.D3XX = D3XX
        self.epin = epin
        self.epout = epout

    def close(self):
        if self.D3XX is not None:
            self.D3XX.close(True)
            self.D3XX = None

    def write(self, bytes, timeout=1000):
        return self.D3XX.writePipe(self.epout, bytes, len(bytes), timeout)

    def read(self, datalen, timeout=1000):
        output = self.D3XX.readPipeEx(self.epin, datalen=datalen, timeout=timeout, raw=True)
        return output['bytes']

    def WaitForDeviceReenumeration(self):
        origValue = ftd3xx.raiseExceptionOnError(False)
        time.sleep(1)
        while (ftd3xx.listDevices() == None):
            time.sleep(1)
        ftd3xx.raiseExceptionOnError(origValue)

        if sys.platform == 'linux':
            count = 0
            while count == 0:
                count = ftd3xx.createDeviceInfoList()

    def ResetChipConfiguration(self):
        # set default chip configuration
        # TODO: Use FT_OPEN_BY_DESCRIPTION to avoid problems with LimeSDR Mini
        # TODO: Only do this in factory/recovery mode, no need to reconfigure all the time 
        D3XX = ftd3xx.create(0, FT_OPEN_BY_INDEX)
        if D3XX is None:
            raise Exception("Failed to open driver: FT60x not found or busy.")

        cfg = D3XX.getChipConfiguration()
        cfg.ProductID = 0x601e
        cfg.bInterval = 0x09
        cfg.PowerAttributes = 0xe0
        cfg.PowerConsumption = 0x60
        cfg.Reserved2 = 0x00
        cfg.FIFOClock = FT_CONFIGURATION_FIFO_CLK_100
        # cfg.FIFOClock = FT_CONFIGURATION_FIFO_CLK_66
        # cfg.FIFOClock = FT_CONFIGURATION_FIFO_CLK_50
        # cfg.FIFOClock = FT_CONFIGURATION_FIFO_CLK_40
        cfg.FIFOMode = FT_CONFIGURATION_FIFO_MODE_245
        cfg.ChannelConfig = FT_CONFIGURATION_CHANNEL_CONFIG_1
        cfg.OptionalFeatureSupport = 0x03c2
        cfg.BatteryChargingGPIOConfig = 0xe4
        cfg.MSIO_Control = 0x00010800

        D3XX.setChipConfiguration(cfg)
        D3XX.close(True)
        D3XX = 0

        # wait until device has reenumerated
        self.WaitForDeviceReenumeration()

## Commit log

2018-11-28 Initial commit: WIP
    [Kilsyth.kicad_pcb, Kilsyth.sch, power.sch]
2018-12-02 More progress
    [Kilsyth.kicad_pcb, Kilsyth.sch]
2018-12-02 more wip
    [Kilsyth.sch]
2018-12-04 fixed footprints
2018-12-06 yarrr. fixed imoprtant pmic bug
    [Kilsyth.kicad_pcb, Kilsyth.sch]
2018-12-07 Some progress
    [Kilsyth.kicad_pcb]
2018-12-07 Keep out
    [Kilsyth.kicad_pcb]
2018-12-08 before r0 hell
    [Kilsyth.kicad_pcb, Kilsyth.sch]
2018-12-09 getting somewhere
    [Kilsyth.kicad_pcb, Kilsyth.sch]
2018-12-09 Final RevA
    [Kilsyth.kicad_pcb, Kilsyth.sch]
2018-12-09 Final touches
    [Kilsyth.kicad_pcb]
2018-12-09 Changed from 4 to 5 mil spacing.. HELL.
    [Kilsyth-B.Cu.gbr, Kilsyth-B.Mask.gbr, Kilsyth-B.Paste.gbr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]
2018-12-10 Last minute changes
    [Kilsyth-B.Cu.gbr, Kilsyth-B.Mask.gbr, Kilsyth-B.Paste.gbr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]
2018-12-10 Last minute again.. lol
    [Kilsyth-B.Cu.gbr, Kilsyth-B.Mask.gbr, Kilsyth-B.Paste.gbr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]
2018-12-10 Final final touches
    [Kilsyth-B.Cu.gbr, Kilsyth-B.Mask.gbr, Kilsyth-B.Paste.gbr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]
2018-12-10 Final final final touches
    [Kilsyth-B.Cu.gbr, Kilsyth-B.Mask.gbr, Kilsyth-B.Paste.gbr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]
2018-12-10 Minor cosmetic changes and BOM stuff.
    [Kilsyth.kicad_pcb, Kilsyth.sch]
2018-12-11 Move files to hardware
    [Kilsyth-B.Cu.gbr, Kilsyth-B.Mask.gbr, Kilsyth-B.Paste.gbr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]
2018-12-11 Add errata
    [Kilsyth.sch]
2018-12-11 more errata
    [Kilsyth.sch]
2018-12-18 Add BODGE information
    [Kilsyth.sch]
2018-12-18 Don't Look: fix path
    [kilsyth.cfg]
2018-12-18 Fix paths
    [kilsyth.cfg]
2018-12-21 Clean up the schematic a bit
    [Kilsyth.sch]
2018-12-21 Add errata for JTAG connector
    [Kilsyth.sch]
2018-12-21 Trellis and cleanup
    [kilsyth_lfe5u12.cfg]
2018-12-23 Simple Kilsyth board file and example
    NOTE:
    Needs a hack to migen to pass the --idcode to get a usable bitstream!
2018-12-25 Add nasty closed source driver example code + mods
2019-01-11 Support all lfe5uXX targets
    [kilsyth_lfe5u25.cfg, kilsyth_lfe5u45.cfg, kilsyth_lfe5u85.cfg]
2019-01-12 First steps with python glue
2019-01-12 Vendor ft60x python driver
2019-01-12 PATCH: Add support for 50, 40 MHz in prints
2019-06-08 Add FT600 module and some applets
    - SX1257 RX applet
    - SPI slate applet
2019-06-16 Integrate FTD3xx lib and clean up old stuff
    [kilsyth_bootloader_vho.sdf]
2019-10-11 Move RevA to its own directory
    [Kilsyth-B.Cu.gbr, Kilsyth-B.Mask.gbr, Kilsyth-B.Paste.gbr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]
2019-10-11 RevB initial draft
    [Kilsyth.kicad_pcb, Kilsyth.sch]
2019-10-11 Add usb-c-breakout
    [Kilsyth.kicad_pcb, Kilsyth.sch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]
2019-10-18 Add CircuitPython ECP5Prog
2019-11-06 Add SiPEED config
    [SiPEED.cfg]
2020-06-28 Add logic analyzer (la) applet. 16CH 100MHz
2020-06-28 Sample 8ch at 100MS/s and indicate fifo overflow
2020-07-25 Add note about USB2422
    [Kilsyth.sch]
